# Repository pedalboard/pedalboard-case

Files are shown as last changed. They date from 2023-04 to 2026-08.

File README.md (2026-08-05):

# pedalboard-case

Mechanical 3D models enclosing the hardware.

The parts are created with openscad 2021.01

## Parts

<table>
<tr>
    <th>Part</th>
    <th>Description</th>
    <th>Image</th>
</tr>
<tr>
    <td><a href="./generated/side-panel-template.pdf">Side Panel Drill Template</a></td>
    <td>
       1:1 printable PDF for marking all side panel and back panel holes:
       6 jack holes (10mm), 2 MIDI/3.5mm holes (6mm), USB-A slot (8mm drill),
       and barrel jack (8mm). Align to top edge of case.
       Regenerate with <code>python3 parts/side-panel-template.py</code>.
    </td>
    <td></td>
</tr>
<tr>
    <td><a href="./generated/display-cutout-template.pdf">Front Panel Cutting Template</a></td>
    <td>
       1:1 printable PDF for marking all front panel holes: 6 button holes (ø22.3mm),
       2 encoder holes (ø22.3mm), 2 display cutouts (34.5×36.7mm), 2 light pipe holes (ø6mm),
       and 8 bezel mount holes (ø4mm). Print at 100% scale on A4.
    </td>
    <td></td>
</tr>
<tr>
    <td><a href="./parts/top-panel-gcode.py">CNC G-code</a></td>
    <td>
       G-code for CNC milling the top panel. Default: 4mm single flute downcut,
       300mm/min feed, 0.3mm depth/pass. Origin: case center (probe both sides).
       Regenerate with <code>python3 parts/top-panel-gcode.py</code>.
    </td>
    <td></td>
</tr>
<tr>
<tr>
    <td><a href="./parts/top-panel-engraving.yaml">Engraving Design</a></td>
    <td>
       Panel label engraving for the powder-coated top surface.
       Button labels A–F, encoder labels Vol/Gain, LED labels Mode/Mon,
       and I/O labels on all four edges. V-bit engraving with surface
       height map compensation via <a href="https://github.com/laenzlinger/plates">plates</a>.
       Run <code>python3 cnc/engrave-setup.py</code> to probe the surface
       and generate <code>engraving.nc</code>.
    </td>
    <td></td>
</tr>
<tr>
    <td><a href="./generated/actuator-assembly.stl">Switch Actuator</a></td>
    <td>
       <a href="https://www.cliffuk.co.uk/products/switches/FC7125.pdf">Manufactured by Cliff</a>.
    </td>
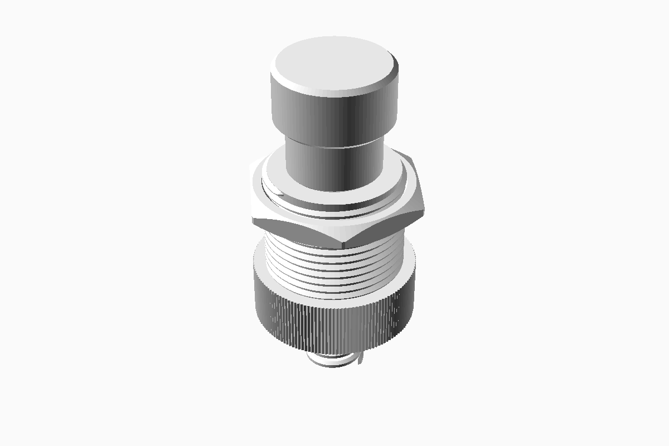
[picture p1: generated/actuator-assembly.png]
    <td></td>
</tr>
<tr>
    <td><a href="./generated/led-ring-washer.stl">Button Washer</a></td>
    <td>
       LED ring washer for Switch Actuator. Print with transparent PETG.
    </td>
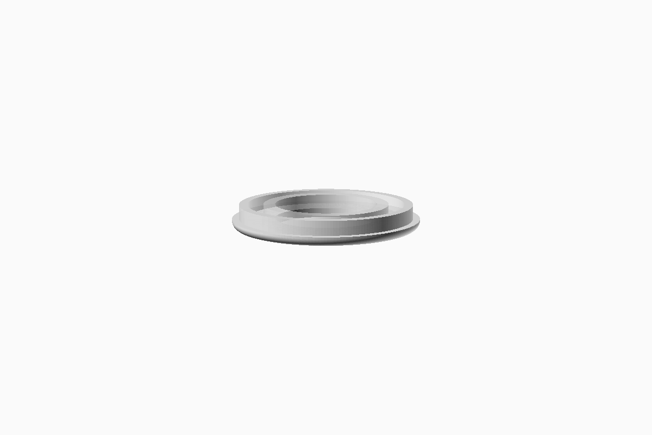
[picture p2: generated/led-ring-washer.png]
    <td></td>
</tr>
<tr>
    <td><a href="./generated/led-ring-rotary-washer.stl">Rotary Encoder Washer</a></td>
    <td>
       LED ring washer for Rotary Encoder. Print with transparent PETG.
    </td>
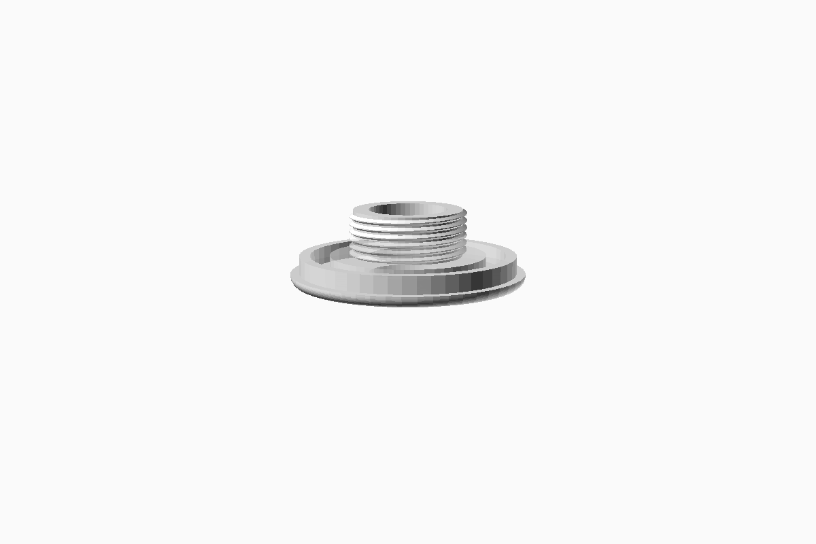
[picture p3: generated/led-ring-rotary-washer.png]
    <td></td>
</tr>
<tr>
    <td><a href="./generated/light-pipe.stl">Light Pipe</a></td>
    <td>
       Print with transparent PETG.
    </td>
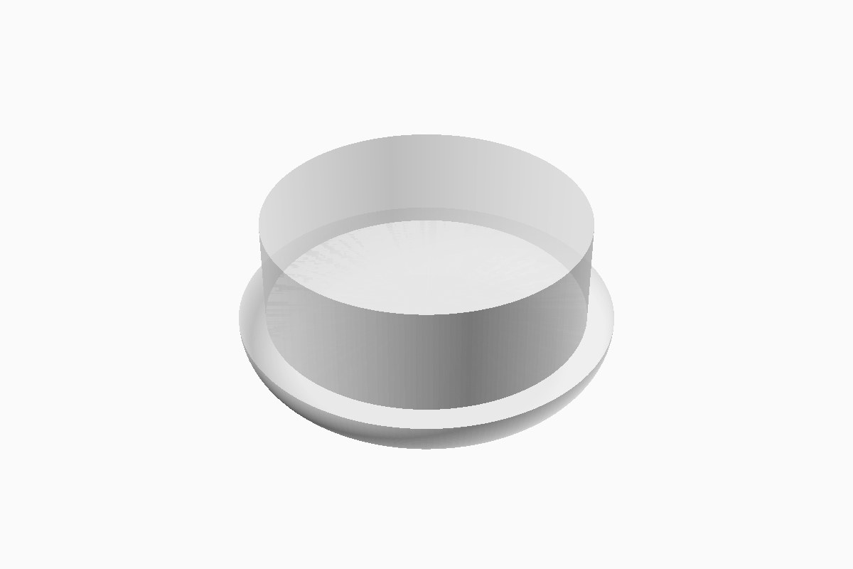
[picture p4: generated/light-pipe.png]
    <td></td>
</tr>

<tr>
    <td><a href="./generated/display-bezel.stl">Display Bezel</a></td>
    <td>
       Display bezel for 128x128 pixel OLED Display (1.5")
    </td>
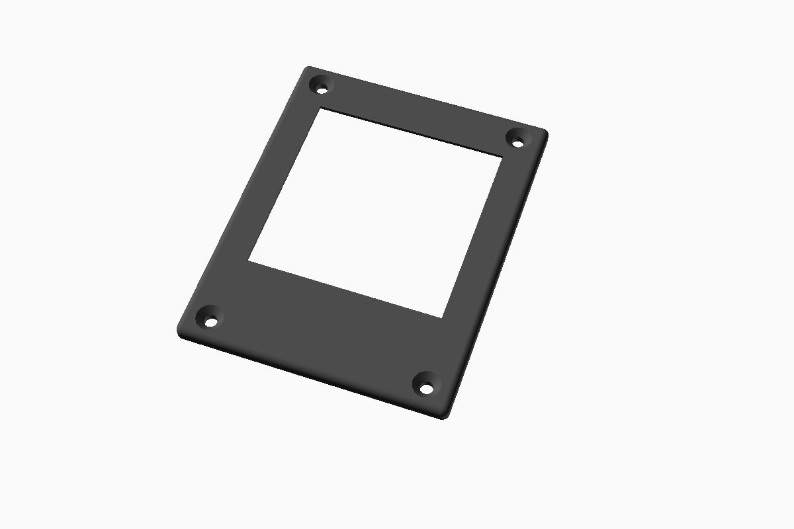
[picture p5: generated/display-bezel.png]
    <td></td>
</tr>
 <tr>
    <td><a href="./generated/display-mounting-rack.stl">Display Mounting Rack</a></td>
    <td>
       Display mounting rack for 128x128 pixel OLED Display (1.5")
    </td>
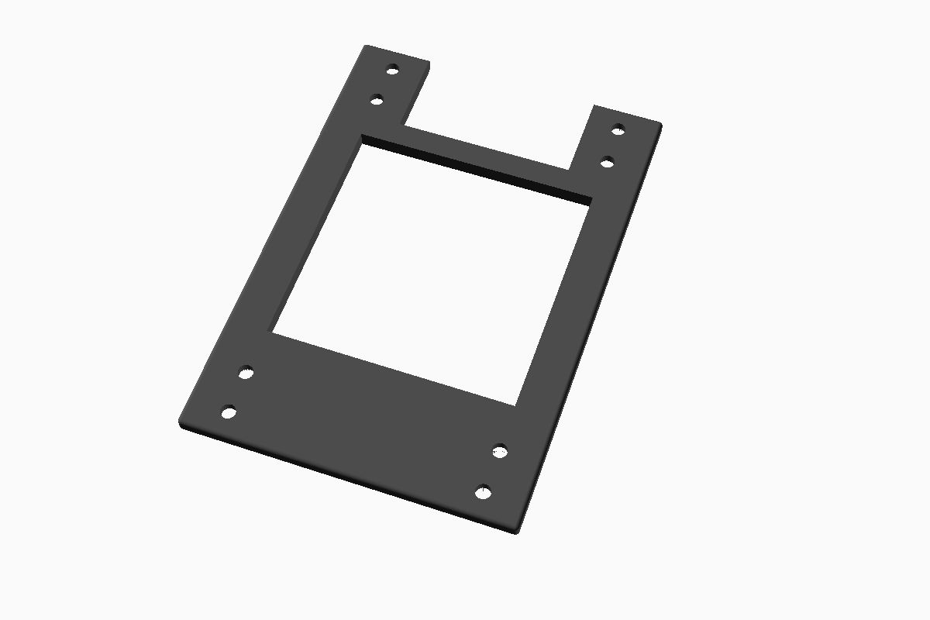
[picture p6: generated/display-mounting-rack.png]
    <td></td>
</tr>
<tr>
    <td><a href="./generated/oled-display.stl">OLED Display</a></td>
    <td>
      Model of the 128x128 pixel OLED display (1.5")
    </td>
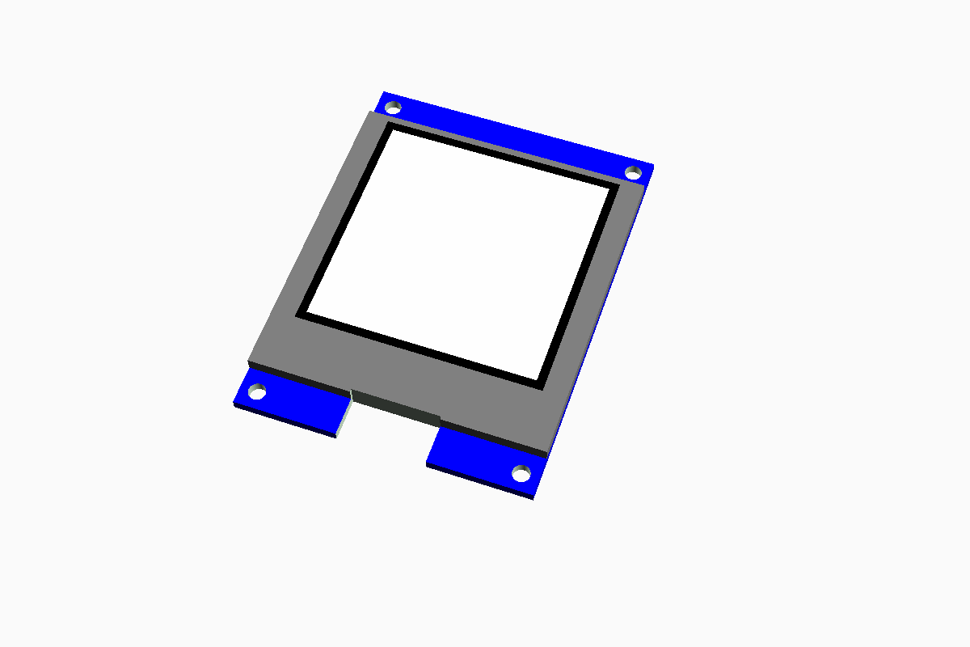
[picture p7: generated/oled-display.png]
    <td></td>
</tr>
 <tr>
    <td><a href="https://github.com/laenzlinger/cnc/tree/main/parts/fixture-plate">CNC Fixture Plate</a></td>
    <td>
       15mm MDF fixture plate for milling the top panel on the SRcnc.
       Maintained in the <a href="https://github.com/laenzlinger/cnc">cnc repo</a>.
    </td>
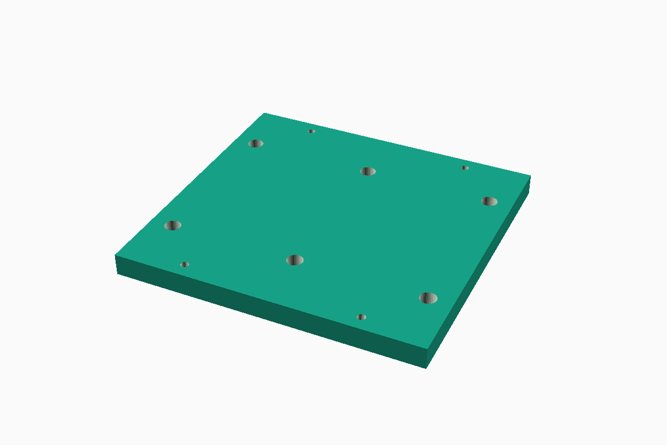
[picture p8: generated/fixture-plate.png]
    <td></td>
</tr>
<tr>
    <td><a href="./parts/led-ring-flush.scad">LED Ring (flush mount)</a></td>
    <td>
       2mm plexiglass stepped ring for flush-mounted LED illumination.
       ø24mm top lip (1mm) sits in case recess, ø22mm bottom (1mm) drops into button hole,
       ø14mm center hole for actuator. Acts as light diffuser for SK6805-EC15 LEDs.
       CNC cut from plexiglass sheet with 4mm downcut endmill.
    </td>
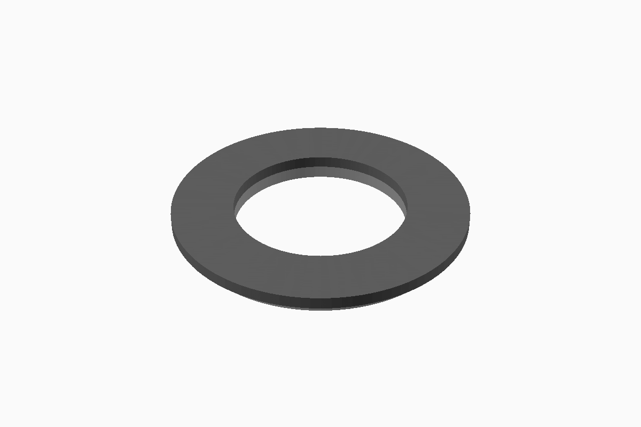
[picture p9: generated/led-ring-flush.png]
    <td></td>
</tr>
<tr>
    <td><a href="./parts/display-window-flush.scad">Display Window (flush mount)</a></td>
    <td>
       2mm plexiglass stepped rectangle for flush-mounted OLED display.
       36.5×38.7mm top lip (1mm) sits in case recess, 34.1×36.3mm bottom (1mm) drops into
       display cutout. Solid window — display visible through plexiglass.
       2mm corner radius (4mm endmill). CNC cut from plexiglass sheet.
    </td>
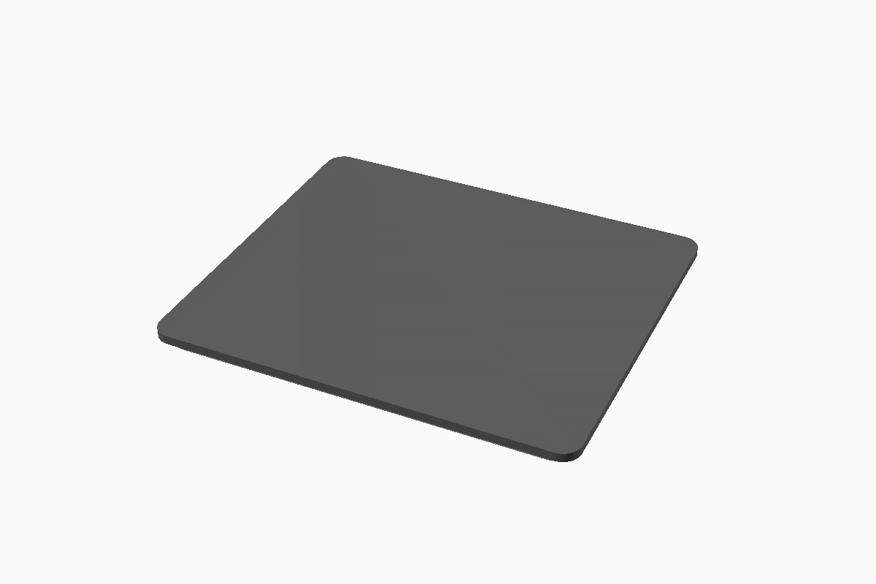
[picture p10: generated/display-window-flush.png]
    <td></td>
</tr>
<tr>
    <td><a href="./parts/lightpipe-disc.scad">Light Pipe Disc (flush mount)</a></td>
    <td>
       2mm plexiglass disc for flush-mounted light pipe.
       6mm diameter, press-fits into light pipe hole.
       CNC cut from plexiglass sheet with 4mm downcut endmill.
    </td>
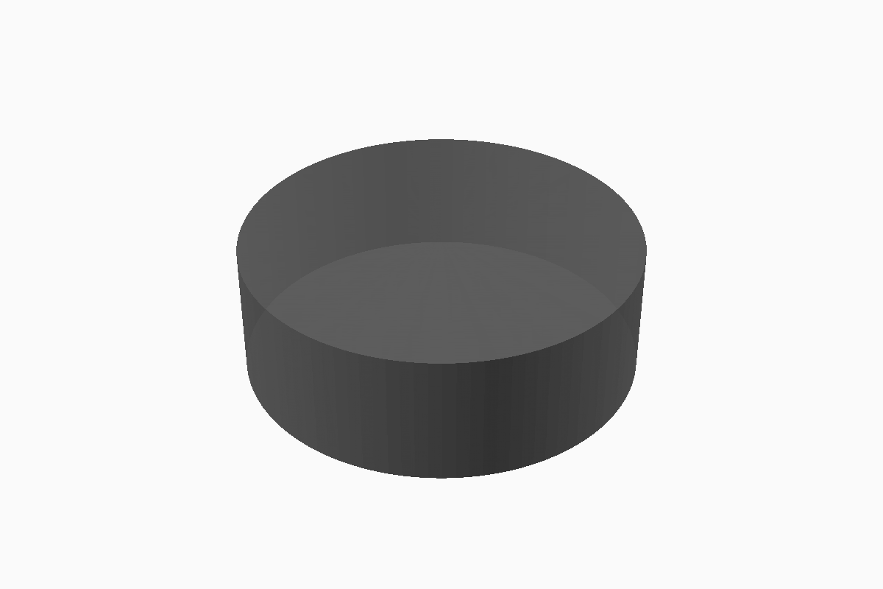
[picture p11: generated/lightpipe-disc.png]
    <td></td>
</tr>
</table>

## 3D printable files

See [STL files](./generated)

Some parts are available in two variants:

| Function | 3D printed (PETG) | CNC plexiglass |
|---|---|---|
| Button LED ring | `led-ring-washer.stl` | `led-ring-flush.scad` |
| Encoder LED ring | `led-ring-rotary-washer.stl` | `led-ring-flush.scad` |
| Display window | `display-bezel.stl` + mounting rack | `display-window-flush.scad` |
| Light pipe | `light-pipe.stl` | `lightpipe-disc.scad` |

**3D printed** — uses transparent PETG, easier to make, rougher finish.
Good for prototyping.

**CNC plexiglass** — cut from 2mm translucent acrylic sheet, flush-mount
with stepped profile, cleaner look. Requires CNC and `plexi-cut.py`.

## Top panel generation

All top panel machining outputs are derived from the [pedalboard-display](https://github.com/pedalboard/pedalboard-display) KiCad PCB:

```
pedalboard-display.kicad_pcb
  → extract-coords.py → top-panel-coords.json
  → top-panel-gcode.py → top-panel.nc
  → top-panel-template.py → display-cutout-template.svg/.pdf
```

Regenerate after PCB changes:

```bash
cd parts && make panel
```

## CNC milling workflow

The top panel is milled on the SRcnc machine (Hammond 1590DD die cast aluminium,
open-side-down fixture). Two separate operations: hole cutting, then engraving.

See [cnc/README.md](./cnc/README.md) for full setup instructions, probing geometry,
and testing.

### 1. Cut holes

```bash
cd cnc
python3 probe-setup.py    # close gSender first — script owns the serial port
# → generates top-panel.nc
# Open gSender, load top-panel.nc, dial 1, WD-40, run at 150% feed
```

Tool: 4mm single flute downcut, 300mm/min, 0.3mm depth/pass.

### 2. Engrave labels

```bash
python3 engrave-setup.py  # close gSender first
# → probes 6×10 surface height map, generates engraving.nc
# Open gSender, load engraving.nc, run
```

Tool: 60° V-bit, 150mm/min. The height map compensates for powder coat
variation and panel crown so the V-bit follows the actual surface.
`engrave-setup.py` runs independently — no need to run `probe-setup.py` first.

**Manual G-code generation (without height map):**

```bash
python3 parts/top-panel-gcode.py --angle -0.23 --z-offsets z-offsets.json > top-panel.nc
```

**Origin modes:**
- `center` (default) — G54 X0 Y0 at case center, requires probing edges
- `corner` — G54 X0 Y0 at front-left corner of case top surface

## Plexiglass parts

All flush-mount plexiglass parts (LED rings, display windows, light pipe discs)
are cut from 2mm acrylic sheet (translucent black tea / smoke).

**Generate G-code:**

```bash
# Test cut (1 of each part)
python3 parts/plexi-cut.py > generated/plexi-cut.nc

# Production (8 rings, 2 windows, 2 discs)
python3 parts/plexi-cut.py --production > generated/plexi-production.nc
```

**Cutting parameters:**
- Tool: 4mm single flute downcut
- Spindle: Makita dial 3 (~17,000 RPM)
- Feed: 500 mm/min
- Depth/pass: 0.25mm
- Fixture: double-sided tape, leave protective film on

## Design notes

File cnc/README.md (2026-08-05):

# cnc/

Automated CNC setup scripts for the Hammond 1590DD top panel —
hole cutting and engraving on powder-coated aluminium.

## Files

| File | Purpose |
|---|---|
| `grbl.py` | Shared GRBL/grblHAL serial protocol and probe helpers |
| `probe-setup.py` | Full setup for hole cutting: edges, angle, per-feature Z, G-code |
| `engrave-setup.py` | Setup for engraving: edges, angle, surface height map, engraving G-code |
| `mock-machine.py` | Machine simulator for testing without real hardware |
| `run_test.py` | Test runner (runs setup scripts against simulator) |

## Setup

```bash
pip install pyserial==3.5
```

## Workflow Overview

```
1. Mount case on fixture plate (open-side-down, centered at ~X=110 Y=190)
2. Close gSender

── HOLE CUTTING ──────────────────────────────────────────────────────────────
3. python3 cnc/probe-setup.py
   → installs 3D probe, finds centre+angle, per-feature Z offsets, touch plate Z
   → generates top-panel.nc
4. Open gSender, connect, load top-panel.nc, run

── ENGRAVING ─────────────────────────────────────────────────────────────────
5. python3 cnc/engrave-setup.py
   → installs 3D probe, finds centre+angle, probes 6×10 height map (38 points),
     skips holes, saves heightmap.json, generates engraving.nc via plates.py
   → installs V-bit, touch plate Z
6. Open gSender, connect, load engraving.nc, run
```

---

## probe-setup.py

Full automated setup for hole cutting.

**Usage:**
```bash
python3 probe-setup.py                     # full run
python3 probe-setup.py --dry-run           # print commands without connecting
python3 probe-setup.py --port /tmp/cnc-sim # test with simulator

# Rework (holes already cut — skip feature probing):
python3 probe-setup.py --skip-feature-probing --z-probe-offset 10 0
```

**Steps:**
1. Home machine (Z → X → Y)
2. Pause: install 3D probe
3. Probe spoilboard Z reference
4. Probe 5 case edges → centre + rotation angle, set G54 X0 Y0
5. Probe case surface Z at centre
6. Probe Z at 12 feature centres (buttons, encoders, displays, LEDs)
7. Pause: swap to cutting tool
8. Probe Z with touch plate → set G54 Z0
9. Generate `top-panel.nc` with angle + Z offsets

**Outputs:** `top-panel.nc`, `z-offsets.json`

---

## engrave-setup.py

Setup for engraving on the powder-coated panel surface.

The powder coat is non-conductive and ~0.1mm thick — the 3D mechanical
probe measures the actual coated surface. A 6×10 height map grid is probed
across the panel (~20mm spacing), skipping all hole positions. The height map
is applied to the engraving G-code via `plates.py --heightmap` so the V-bit
follows the actual surface rather than a flat plane.

**Usage:**
```bash
python3 engrave-setup.py                     # full run
python3 engrave-setup.py --dry-run           # print commands without connecting
python3 engrave-setup.py --port /tmp/cnc-sim # test with simulator

# If case centre has a hole (use an offset reference point):
python3 engrave-setup.py --z-probe-offset 10 0
```

**Steps:**
1. Home machine (Z → X → Y)
2. Pause: install 3D probe
3. Probe spoilboard Z reference
4. Probe 5 case edges → centre + rotation angle, set G54 X0 Y0
5. Probe reference surface Z at centre
6. Probe 6×10 grid (38 points after skipping holes) → `heightmap.json`
7. Generate `engraving.nc` via `plates.py --heightmap`
8. Pause: swap to V-bit
9. Probe Z with touch plate → set G54 Z0

**Outputs:** `engraving.nc`, `heightmap.json`

### Height Map Grid

```
Grid: 6 cols × 10 rows  (~20mm spacing)
Bounds: ±53.9mm X, ±87.9mm Y (3mm margin from each edge)
Hole avoidance: buttons/encoders r=14.2mm, LEDs r=6mm,
                bezel holes r=5mm, displays 25×21mm rect
Skipped points filled by nearest-neighbour for complete JSON grid.
```

---

## mock-machine.py

GRBL/grblHAL machine simulator for testing without real hardware.

```bash
python3 mock-machine.py                       # nominal case
python3 mock-machine.py --angle 0.5           # 0.5° rotation
python3 mock-machine.py --offset-x 2.0        # case shifted 2mm in X
python3 mock-machine.py --crown 0.3           # 0.3mm sinusoidal surface crown
python3 mock-machine.py --angle 0.3 --crown 0.4  # combined
```

The `--crown` option simulates a typical die-cast aluminium panel: the surface
is highest at the centre and tapers to zero at the edges following a
cosine profile. Typical powder-coated cases: 0.3–0.5mm.

---

## Testing

```bash
make test           # run probe-setup.py against simulator
make test-engrave   # run engrave-setup.py against simulator (with 0.3mm crown)

# Manual testing with custom parameters:
python3 run_test.py --angle 0.5
python3 run_test.py --engrave --crown 0.5
```

### Testing with two terminals

```bash
# Terminal 1 — start simulator
python3 mock-machine.py --angle 0.3 --crown 0.3

# Terminal 2 — run setup
python3 probe-setup.py --port /tmp/cnc-sim
# or
python3 engrave-setup.py --port /tmp/cnc-sim
```

---

## XY Probing Geometry

Same for both scripts — 5 edge probes, no case dimension assumptions:

```
              You stand here (Y=0)

    Y
    ↑
    │
    ┊                  ┌───────────────────────┐
250 ┊ ─ ─ ─ ②·→→→→→→→→→█           ·⑤          │
    │                  │       X=110,Y=291     │
190 ┊                  │       CENTER          █←·③
    │                  │     (110, 190)        │ X=177
130 ┊ ─ ─ ─ ①·→→→→→→→→→█                       │
    ┊                  └───────────────────────┘
 89 ┊                          ·④
    └──────────────────────────── → X
   0      43  53              167 177  220

  ① X- front  Y=130  → +X   left edge + angle pt 1
  ② X- back   Y=250  → +X   left edge + angle pt 2
  ③ X+ edge   Y=190  ← -X   right edge
  ④ Y- edge   X=110  ↑ +Y   front edge
  ⑤ Y+ edge   X=110  ↓ -Y   back edge

  X centre = (avg(①,②) + ③) / 2
  Y centre = (④ + ⑤) / 2
  Angle    = atan2(②x − ①x, 120mm)
```

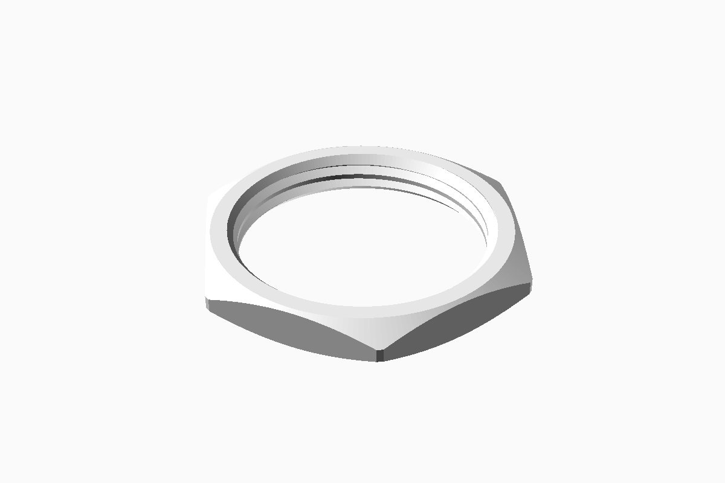
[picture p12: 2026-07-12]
generated/actuator-nut.png

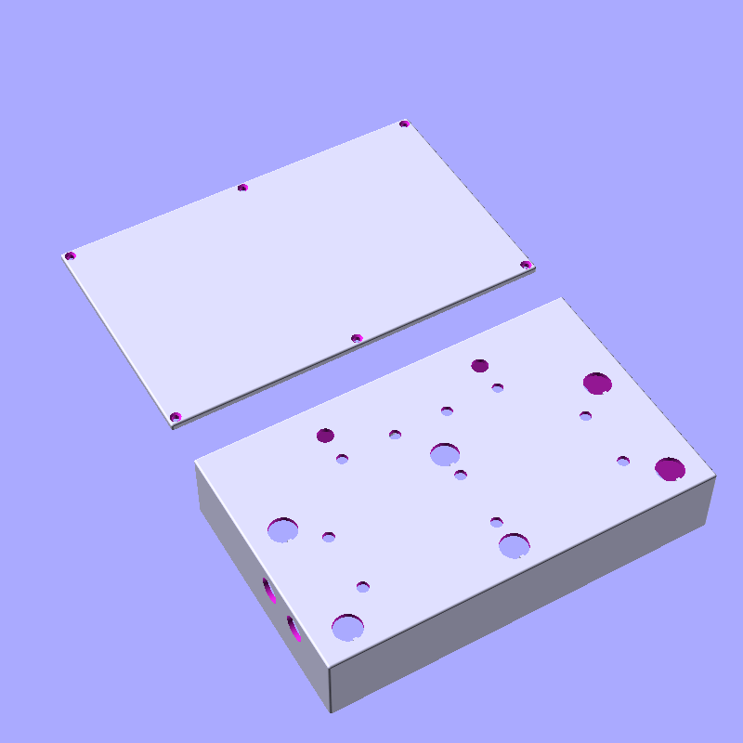
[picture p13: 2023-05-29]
generated/pedalboard-case.png

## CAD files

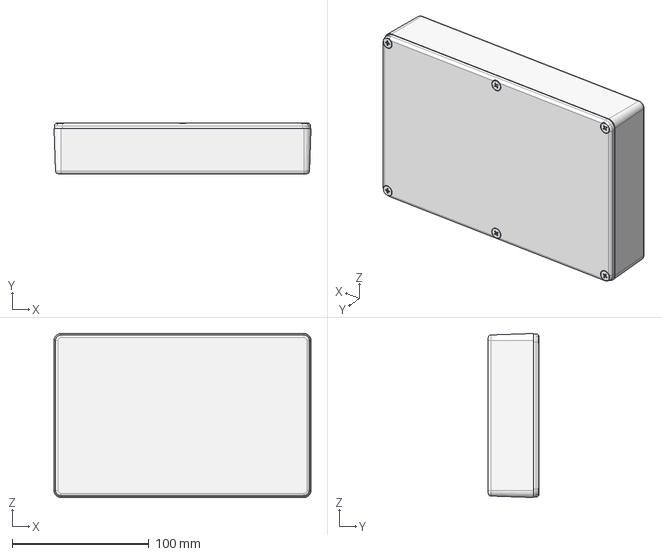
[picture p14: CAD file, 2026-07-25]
1590DD.stp
188.0 x 37.0 x 120.0 mm

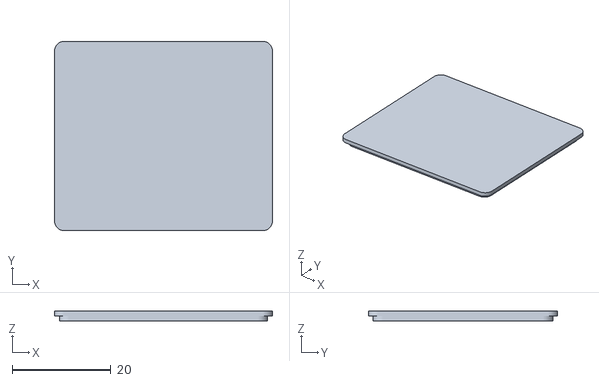
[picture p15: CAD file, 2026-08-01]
generated/display-window-flush.stl
44.2 x 38.4 x 2.00

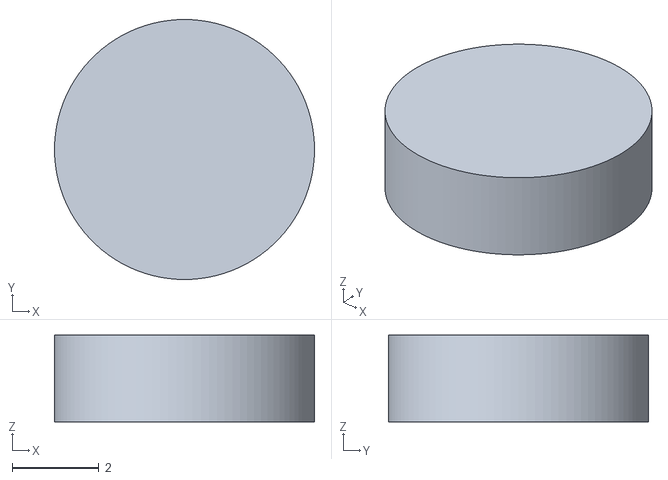
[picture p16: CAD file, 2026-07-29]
generated/lightpipe-disc.stl
6.00 x 6.00 x 2.00

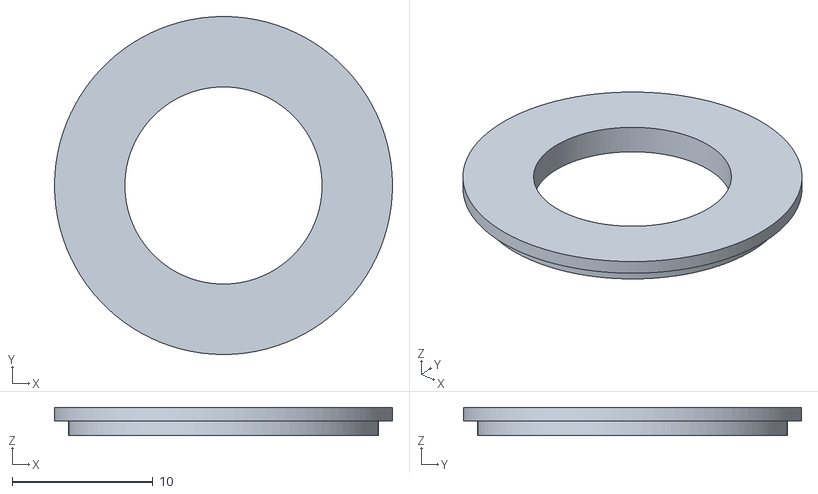
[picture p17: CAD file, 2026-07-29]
generated/led-ring-flush.stl
24.0 x 24.0 x 2.00

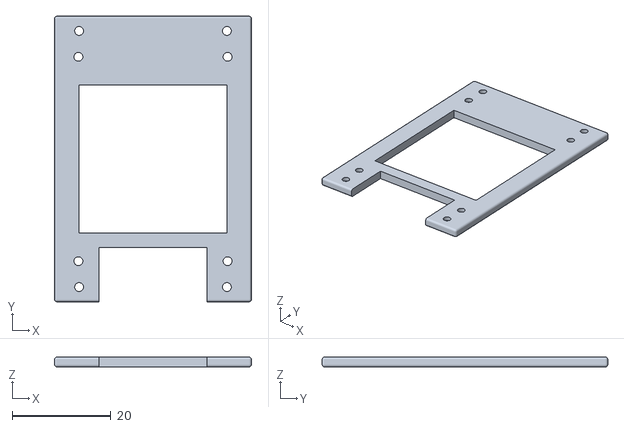
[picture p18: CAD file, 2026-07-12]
generated/display-mounting-rack.stl
40.0 x 58.0 x 2.00

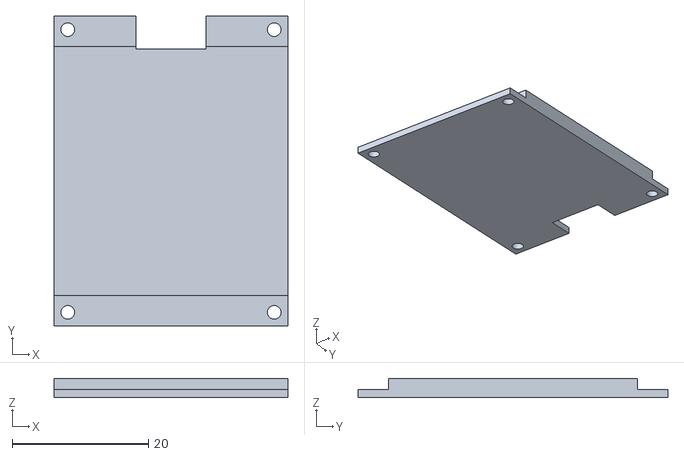
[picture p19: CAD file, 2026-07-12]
generated/oled-display.stl
34.3 x 45.5 x 2.83

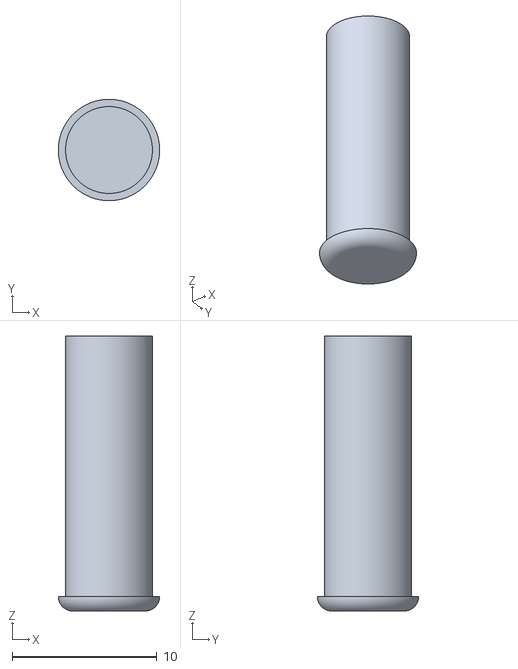
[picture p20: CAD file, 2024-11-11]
generated/light-pipe.stl
7.00 x 7.00 x 19.0

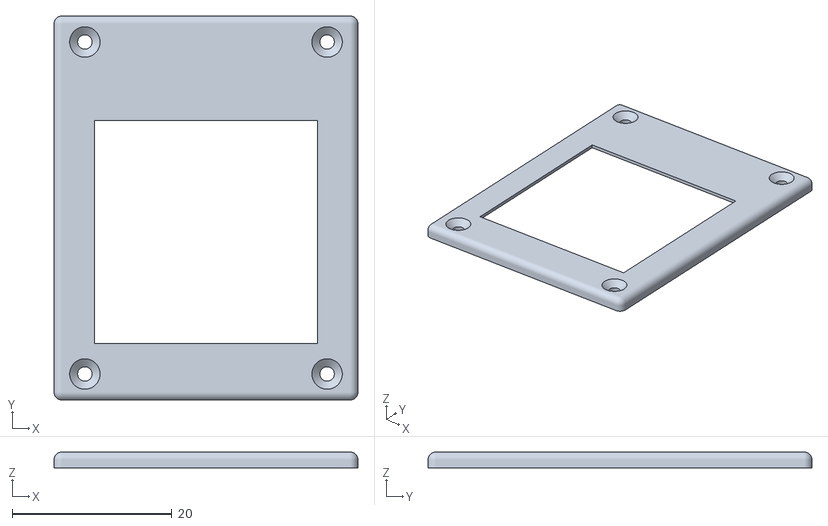
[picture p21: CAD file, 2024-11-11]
generated/display-bezel.stl
38.0 x 48.0 x 2.00

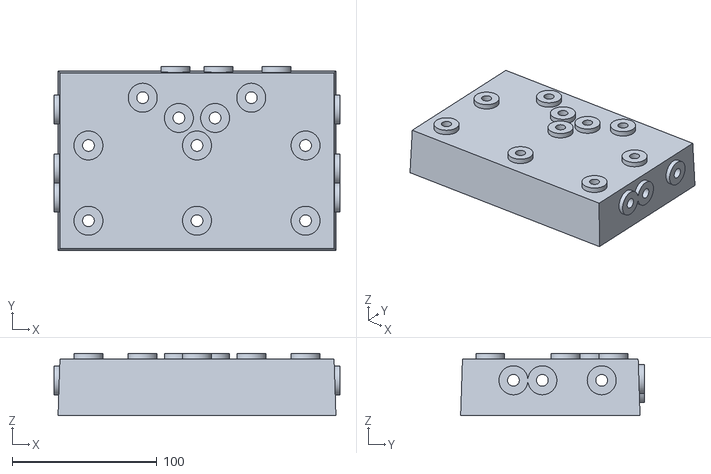
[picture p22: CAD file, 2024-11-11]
generated/drill-jig.stl
197.6 x 127.0 x 43.0

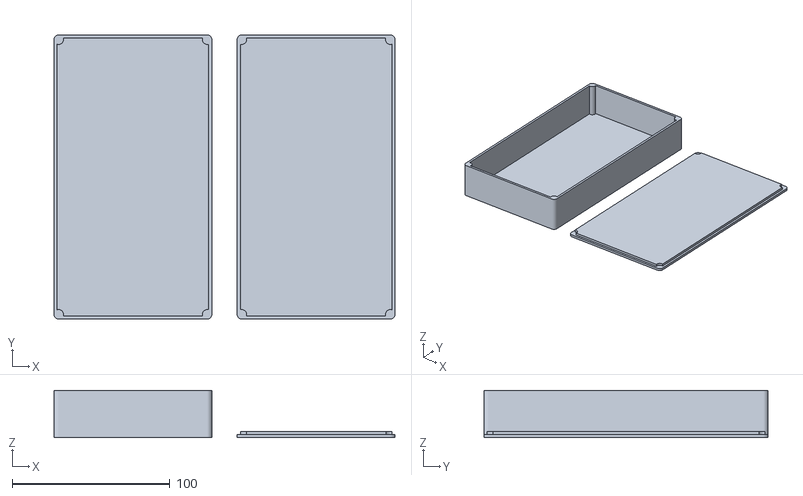
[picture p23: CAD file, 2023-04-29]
generated/pedalboard-case.stl
216.0 x 180.0 x 30.0

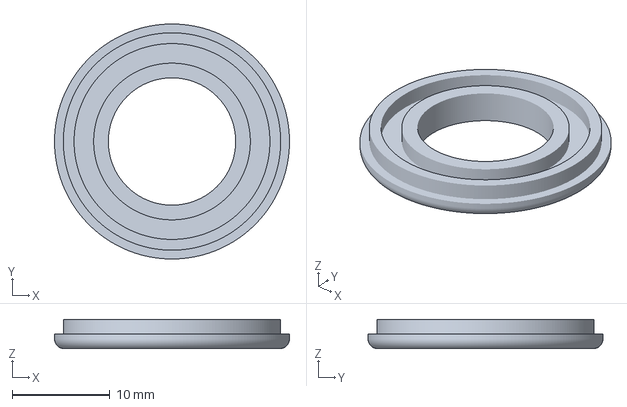
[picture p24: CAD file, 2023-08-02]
slicer/led-ring-washer.3mf
24.0 x 24.0 x 3.00 mm

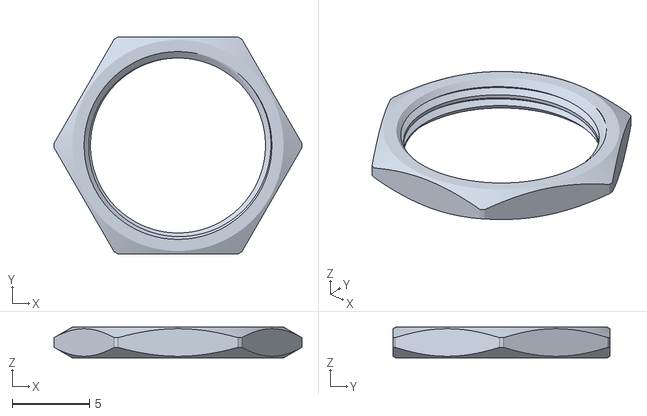
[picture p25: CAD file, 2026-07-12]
generated/actuator-nut.stl
16.0 x 14.0 x 2.00

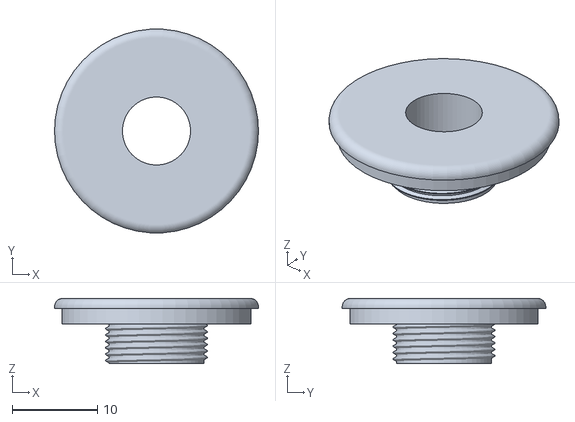
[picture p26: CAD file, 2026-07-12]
generated/led-ring-rotary-washer.stl
24.0 x 24.0 x 7.70

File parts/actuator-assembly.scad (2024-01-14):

include <lib/actuator.scad>

$fn=100;

pcb_thickness = 1.6;

actuator();
up(5+4.5+pcb_thickness) actuator_nut();
// up(5+2.5+pcb_thickness) led_ring_washer();

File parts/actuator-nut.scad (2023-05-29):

include <lib/actuator.scad>

$fn=200;

actuator_nut();

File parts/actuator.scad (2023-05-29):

include <BOSL2/std.scad>
include <BOSL2/threading.scad>

// based on https://www.cliffuk.co.uk/products/switches/FC7125.pdf

$fn=200;

module actuator() {
    screwlen = 14.3;
    up(screwlen/2) threaded_rod(d=12,l=screwlen,pitch=0.75);
    up(screwlen+2.05+5) cyl(l=5.1, d=10, chamfer=0.4);
    up(screwlen+2.6) cyl(l=5.2, d=8, chamfer=0.2);
    up(2.5) cyl(l=5, d=14, texture="ribs", tex_scale=0.1, tex_size=[0.3,0.3]);
    down(3) thread_helix(d2=3, d1=4.8, pitch=1, thread_depth=0.3, flank_angle=35, turns=6.5);
}

actuator();

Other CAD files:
parts/display-bezel.scad
parts/display-mounting-rack.scad
parts/display-window-flush.scad
parts/led-ring-flush.scad
parts/led-ring-rotary-washer.scad
parts/led-ring-washer.scad
parts/light-pipe.scad
parts/lightpipe-disc.scad
parts/oled-display.scad

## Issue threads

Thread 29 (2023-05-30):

Refactoring: Use BOSL2

laenzlinger, 2023-05-30:
BOSL2 supports threads and allows so much nicer code

laenzlinger, 2024-01-09:
no need for refactoring, the case stragety has changed

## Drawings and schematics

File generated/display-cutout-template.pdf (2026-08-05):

# Pedalboard Case Cutting Template (1:1)

Display cutout: 42.5×36.7mm. Print at 100% on A4.

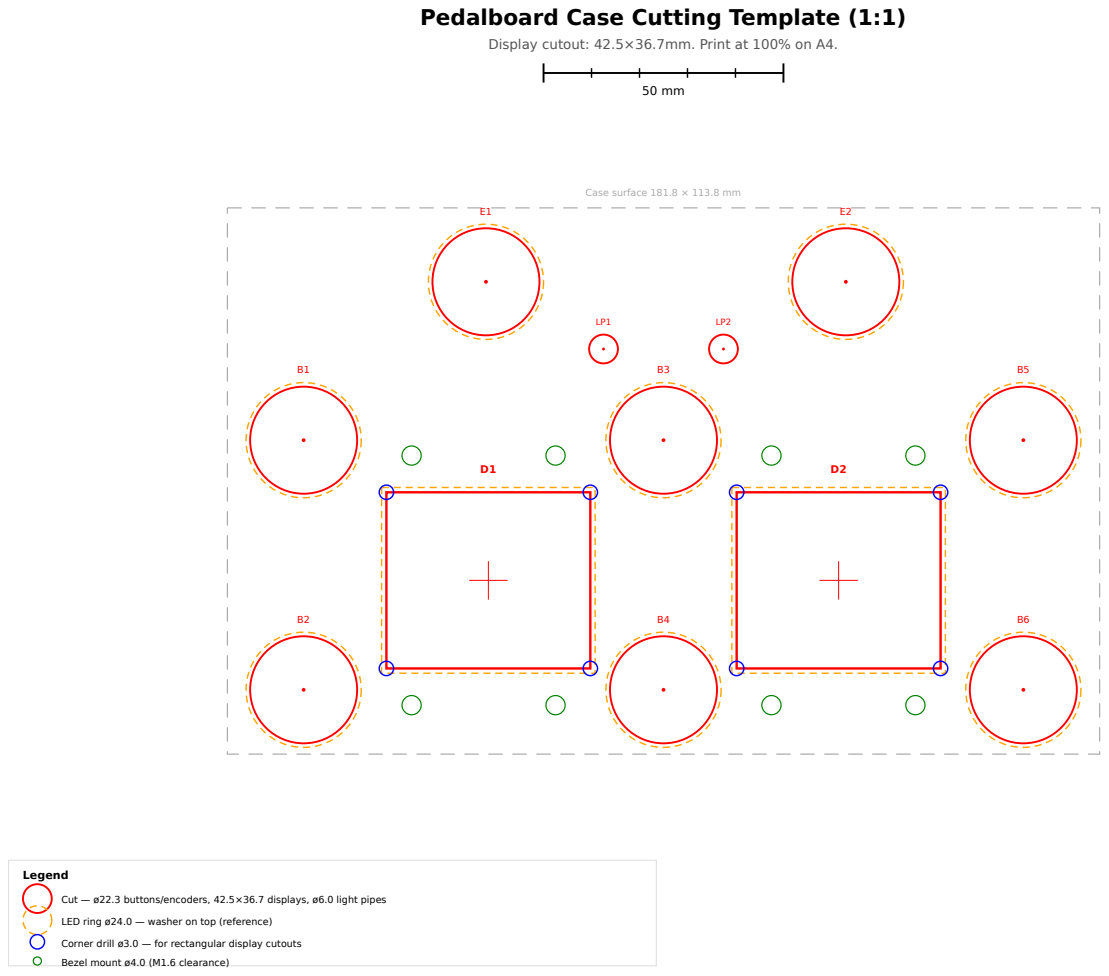
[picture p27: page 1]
Legend

Case surface 181.8 × 113.8 mm

Cut — ø22.3 buttons/encoders, 42.5×36.7 displays, ø6.0 light pipes

LED ring ø24.0 — washer on top (reference)

Corner drill ø3.0 — for rectangular display cutouts
Bezel mount ø4.0 (M1.6 clearance)

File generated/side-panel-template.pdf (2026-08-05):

## Left side (looking from outside) (120mm x 37mm)

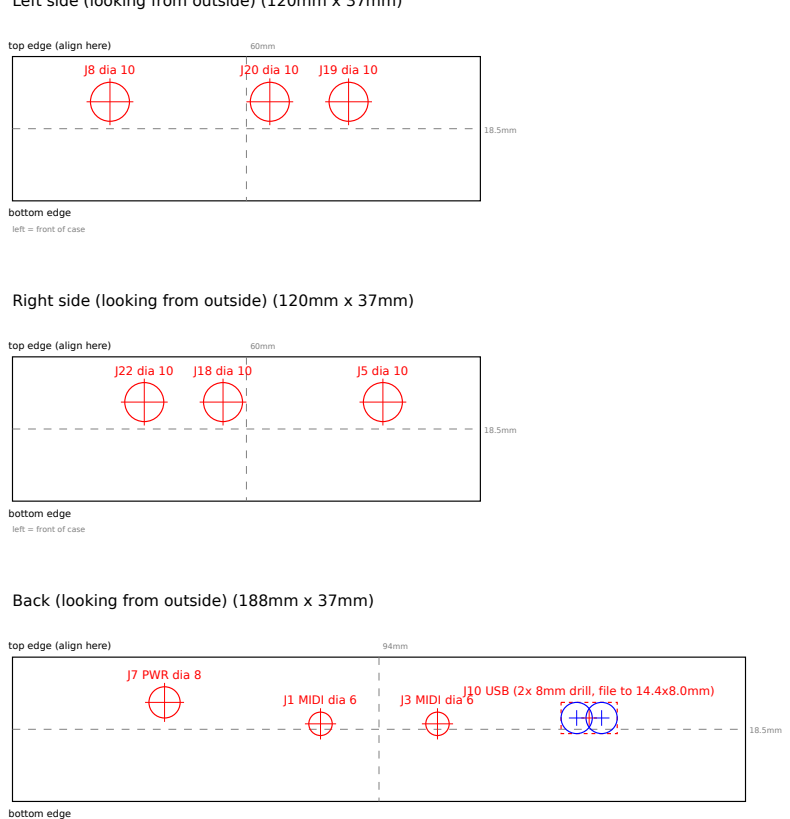
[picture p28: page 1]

top edge (align here)

left = front of case

Right side (looking from outside) (120mm x 37mm)

Back (looking from outside) (188mm x 37mm)

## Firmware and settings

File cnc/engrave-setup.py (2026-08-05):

#!/usr/bin/env python3
"""
engrave-setup.py — Surface height map probing for powder-coated panel engraving.

Probes a grid of Z heights across the Hammond 1590DD top panel surface,
skipping all hole positions. Saves a heightmap.json for use with plates.py
--heightmap to compensate for surface variation when engraving.

Workflow:
  1. Home machine
  2. Pause: install 3D probe
  3. Probe spoilboard Z reference
  4. Probe X-, X+, Y-, Y+ edges → case center + rotation angle, set G54 X0 Y0
  5. Probe surface Z at grid points (skipping holes)
  6. Save heightmap.json
  7. Generate engraving.nc via plates.py --heightmap
  8. Pause: remove 3D probe, install V-bit
  9. Probe Z with touch plate, set G54 Z0
  10. Ready to engrave

Usage:
    python3 engrave-setup.py
    python3 engrave-setup.py --dry-run
    python3 engrave-setup.py --port /tmp/cnc-sim   # test with simulator

Preconditions:
    - gSender disconnected (script owns /dev/cnc)
    - Case mounted open-side-down on fixture plate
    - Holes already cut (from probe-setup.py + top-panel.nc run)
    - Machine in idle state
"""

import argparse
import json
import math
import sys
from pathlib import Path

from grbl import (
    HOMING_TIMEOUT,
    GrblConnection,
    check_plausibility,
    pause,
    probe_edge_double,
    probe_spoilboard,
    probe_z_double,
    probe_z_surface,
)

# Add plates project to path (editable install doesn't expose top-level modules)
_PLATES_DIR = Path(__file__).parent / "../../../laenzlinger/plates"
_PLATES_DIR = _PLATES_DIR.resolve()
if _PLATES_DIR.exists() and str(_PLATES_DIR) not in sys.path:
    sys.path.insert(0, str(_PLATES_DIR))

# === MACHINE CONFIGURATION ===

PORT = "/dev/cnc"
BAUD = 115200

SAFE_Z             = 10.0   # mm — safe Z for rapids
GRID_TRAVERSE_Z    =  3.0   # mm — Z above surface for moves between probe points
FEED_FAST          = 100.0  # mm/min
FEED_SLOW          =  20.0  # mm/min
PROBE_TIP_RADIUS   =  2.0   # mm — HLTNC 3D probe tip radius
TOUCH_PLATE_THICKNESS = 19.25  # mm

# Case geometry (machine coords)
CASE_CENTER_X       = 110.0
CASE_CENTER_Y       = 190.0
CASE_HALF_WIDTH     = 113.8 / 2.0   # X half-extent (short axis)
CASE_HALF_HEIGHT    = 181.8 / 2.0   # Y half-extent (long axis)
CASE_HEIGHT_NOMINAL = 33.0           # mm — case wall height open-side-down
XY_PROBE_BELOW_SURFACE = 5.0

APPROACH_CLEARANCE  = 20.0
PROBE_TRAVEL_Z      = 80.0

ANGLE_PROBE_Y_FRONT = CASE_CENTER_Y - 60.0
ANGLE_PROBE_Y_BACK  = CASE_CENTER_Y + 60.0

TOOL_CHANGE_X = 110.0
TOOL_CHANGE_Y = 5.0

SPOILBOARD_PROBE_X = 10.0
SPOILBOARD_PROBE_Y = 190.0

# Plausibility tolerances
EXPECTED_CASE_WIDTH  = 113.8
EXPECTED_CASE_HEIGHT = 181.8
MAX_WIDTH_ERROR  = 10.0
MAX_ANGLE_DEG    =  5.0
MAX_CENTER_ERROR = 30.0

# === GRID CONFIGURATION ===

# 3mm margin from each edge (inside the 1mm fillet radius + clearance)
GRID_MARGIN = 3.0

# Grid in G54 work coordinates (origin = case centre)
# Panel: 181.8 (Y long) x 113.8 (X short) → half-extents minus margin
GRID_X_HALF = CASE_HALF_WIDTH  - GRID_MARGIN   # 53.9mm
GRID_Y_HALF = CASE_HALF_HEIGHT - GRID_MARGIN   # 87.9mm

# ~20mm spacing → 6 cols x 10 rows = 60 points (38 probed after hole avoidance)
GRID_COLS = 7
GRID_ROWS = 8

# Hole avoidance: probe tip radius + 1mm safety margin
_HOLE_MARGIN = PROBE_TIP_RADIUS + 1.0   # 3.0mm extra

# Paths
SCRIPT_DIR     = Path(__file__).parent
REPO_ROOT      = SCRIPT_DIR.parent
ENGRAVING_YAML = REPO_ROOT / "parts" / "top-panel-engraving.yaml"
HEIGHTMAP_FILE = REPO_ROOT / "heightmap.json"
ENGRAVING_NC   = REPO_ROOT / "engraving.nc"
COORDS_JSON    = REPO_ROOT / "parts" / "top-panel-coords.json"


# === HOLE AVOIDANCE ===

def _build_hole_list(angle_deg: float) -> list:
    """Return list of (type, cx, cy, radius_or_None, half_w_or_None, half_h_or_None).

    All coordinates in G54 work coords (origin at case centre, Y+ = toward back).
    Applies angle correction to match the probed case orientation.

    Coordinate conversion from panel_coords (origin=corner, landscape):
      work_x = panel_x - PANEL_W/2
      work_y = panel_y - PANEL_H/2   (panel Y=0=front, work Y- = front)
    """
    sys.path.insert(0, str(REPO_ROOT / "parts"))
    from panel_coords import load_coords, cnc_coords

    data   = load_coords(str(COORDS_JSON))
    # Use origin=corner to get landscape panel coords, then convert to work coords
    coords = cnc_coords(data, origin="corner", angle_deg=angle_deg)
    feats  = data["features"]

    PANEL_W = data["case"]["top_surface_width"]   # 181.8
    PANEL_H = data["case"]["top_surface_height"]  # 113.8

    def to_work(px, py):
        """Panel coords (origin=front-left, landscape) -> work coords (G54, origin=centre).

        Empirically verified (from panel_coords origin=center cross-check):
          work_x = -(panel_y - PANEL_H/2)   (machine X = short axis = panel Y direction)
          work_y =   panel_x - PANEL_W/2    (machine Y = long axis  = panel X direction)
        """
        return -(py - PANEL_H / 2), px - PANEL_W / 2

    holes = []

    # Circular holes — convert landscape panel coords to work coords
    for ox, oy in coords["buttons"]:
        # coords["buttons"] gives (portrait_cnc_x, portrait_cnc_y)
        # landscape: panel_x = portrait_cnc_y, panel_y = PANEL_H - portrait_cnc_x
        panel_x, panel_y = oy, PANEL_H - ox
        wx, wy = to_work(panel_x, panel_y)
        holes.append(("button", wx, wy,
                      feats["button_hole_diameter"] / 2 + _HOLE_MARGIN, None, None))
    for ox, oy in coords["encoders"]:
        panel_x, panel_y = oy, PANEL_H - ox
        wx, wy = to_work(panel_x, panel_y)
        holes.append(("encoder", wx, wy,
                      feats["encoder_hole_diameter"] / 2 + _HOLE_MARGIN, None, None))
    for ox, oy in coords["single_leds"]:
        panel_x, panel_y = oy, PANEL_H - ox
        wx, wy = to_work(panel_x, panel_y)
        holes.append(("led", wx, wy,
                      feats["lightpipe_hole_diameter"] / 2 + _HOLE_MARGIN, None, None))
    for ox, oy in coords["bezel_holes"]:
        panel_x, panel_y = oy, PANEL_H - ox
        wx, wy = to_work(panel_x, panel_y)
        holes.append(("bezel", wx, wy,
                      feats["bezel_hole_diameter"] / 2 + _HOLE_MARGIN, None, None))

    # Rectangular display cutouts
    dw = 42.5 / 2 + _HOLE_MARGIN
    dh = feats["display_cutout_height"] / 2 + _HOLE_MARGIN
    for ox, oy in coords["displays"]:
        panel_x, panel_y = oy, PANEL_H - ox
        wx, wy = to_work(panel_x, panel_y)
        holes.append(("display", wx, wy, None, dw, dh))

    return holes


def _point_in_hole(gx: float, gy: float, holes: list) -> bool:
    """Return True if (gx, gy) is inside any hole's avoidance zone."""
    for _, hx, hy, r, hw, hh in holes:
        if r is not None:
            if math.hypot(gx - hx, gy - hy) < r:
                return True
        else:
            if abs(gx - hx) < hw and abs(gy - hy) < hh:
                return True
    return False


def build_grid(angle_deg: float) -> tuple:
    """Build the probe grid, returning (xs, ys, grid_points, holes).

    grid_points: list of (col, row, x, y, skip) where skip=True means in a hole.
    xs, ys: the column/row coordinate arrays.
    """
    xs = [round(-GRID_X_HALF + i * 2 * GRID_X_HALF / (GRID_COLS - 1), 4)
          for i in range(GRID_COLS)]
    ys = [round(-GRID_Y_HALF + j * 2 * GRID_Y_HALF / (GRID_ROWS - 1), 4)
          for j in range(GRID_ROWS)]

    holes = _build_hole_list(angle_deg)

    points = []
    for row, gy in enumerate(ys):
        for col, gx in enumerate(xs):
            skip = _point_in_hole(gx, gy, holes)
            points.append((col, row, gx, gy, skip))

    n_probe  = sum(1 for _, _, _, _, s in points if not s)
    n_skip   = sum(1 for _, _, _, _, s in points if s)
    print(f"    Grid: {GRID_COLS}×{GRID_ROWS} = {len(points)} points  "
          f"({n_probe} probed, {n_skip} skipped over holes)")

    return xs, ys, points, holes


# === MAIN ===

def run(args):
    grbl = GrblConnection(args.port, BAUD, dry_run=args.dry_run)

    try:
        # [1] Check machine state
        print("\n[1/9] Checking machine state...")
        if not args.dry_run and args.port == PORT:
            result = subprocess.run(["pgrep", "-f", "gsender"], capture_output=True)
            if result.returncode == 0:
                print("ERROR: gSender is running. Close it first.", file=sys.stderr)
                sys.exit(1)
        grbl.check_state()

        # [2] Home
        print("\n[2/9] Homing machine (Z first for safety)...")
        try:
            grbl.send("$X", timeout=5)
        except (RuntimeError, TimeoutError):
            pass
        grbl.send("$HZ", timeout=HOMING_TIMEOUT)
        grbl.send("$HX", timeout=HOMING_TIMEOUT)
        grbl.send("$HY", timeout=HOMING_TIMEOUT)

        grbl.send("G53 G0 Z0")
        grbl.send(f"G53 G0 X{TOOL_CHANGE_X} Y{TOOL_CHANGE_Y}")
        pause("Install 3D probe (HLTNC). Ensure probe is connected.",
              dry_run=args.dry_run)
        grbl.send("G90")
        grbl.send("G53 G0 Z0")
        print("\n    Checking probe...")
        grbl.confirm_probe_trigger(
            "Touch the 3D probe tip to confirm it triggers.",
            dry_run=args.dry_run)

        # [3] Spoilboard probe
        print("\n[3/9] Probing spoilboard reference surface...")
        spoilboard_z = probe_spoilboard(
            grbl,
            x=SPOILBOARD_PROBE_X, y=SPOILBOARD_PROBE_Y,
            safe_z=SAFE_Z, travel=PROBE_TRAVEL_Z,
        )
        grbl.send("G53 G0 Z0")

        # [4] XY edge probing
        print("\n[4/9] Probing case edges for center and angle...")
        xy_probe_z = spoilboard_z + CASE_HEIGHT_NOMINAL - XY_PROBE_BELOW_SURFACE
        print(f"    XY probe Z: {xy_probe_z:.3f}mm")

        grbl.send(f"G53 G0 X{CASE_CENTER_X - CASE_HALF_WIDTH - APPROACH_CLEARANCE:.3f} Y{ANGLE_PROBE_Y_FRONT:.3f}")
        grbl.send(f"G53 G0 Z{xy_probe_z:.3f}")
        x_minus_front = probe_edge_double(grbl, "X", +1, "X- edge (front)")
        grbl.send("G53 G0 Z0")

        grbl.send(f"G53 G0 X{CASE_CENTER_X - CASE_HALF_WIDTH - APPROACH_CLEARANCE:.3f} Y{ANGLE_PROBE_Y_BACK:.3f}")
        grbl.send(f"G53 G0 Z{xy_probe_z:.3f}")
        x_minus_back = probe_edge_double(grbl, "X", +1, "X- edge (back)")
        grbl.send("G53 G0 Z0")

        grbl.send(f"G53 G0 X{CASE_CENTER_X + CASE_HALF_WIDTH + APPROACH_CLEARANCE:.3f} Y{CASE_CENTER_Y:.3f}")
        grbl.send(f"G53 G0 Z{xy_probe_z:.3f}")
        x_plus = probe_edge_double(grbl, "X", -1, "X+ edge")
        grbl.send("G53 G0 Z0")

        grbl.send(f"G53 G0 X{CASE_CENTER_X:.3f} Y{CASE_CENTER_Y - CASE_HALF_HEIGHT - APPROACH_CLEARANCE:.3f}")
        grbl.send(f"G53 G0 Z{xy_probe_z:.3f}")
        y_minus = probe_edge_double(grbl, "Y", +1, "Y- edge")
        grbl.send("G53 G0 Z0")

        grbl.send(f"G53 G0 X{CASE_CENTER_X:.3f} Y{CASE_CENTER_Y + CASE_HALF_HEIGHT + APPROACH_CLEARANCE:.3f}")
        grbl.send(f"G53 G0 Z{xy_probe_z:.3f}")
        y_plus = probe_edge_double(grbl, "Y", -1, "Y+ edge")
        grbl.send("G53 G0 Z0")

        # [5] Compute center and angle, set G54
        print("\n[5/9] Computing center and angle...")
        x_minus_avg = (x_minus_front + x_minus_back) / 2.0
        center_x    = (x_minus_avg + x_plus) / 2.0
        center_y    = (y_minus + y_plus) / 2.0
        dy          = ANGLE_PROBE_Y_BACK - ANGLE_PROBE_Y_FRONT
        dx          = x_minus_back - x_minus_front
        angle_deg   = math.degrees(math.atan2(dx, dy))

        print(f"    Case center: X={center_x:.4f} Y={center_y:.4f}")
        print(f"    Rotation angle: {angle_deg:.4f}°")

        if not args.dry_run:
            if x_minus_avg >= x_plus:
                raise RuntimeError(
                    f"X- edge ({x_minus_avg:.4f}) is not left of X+ ({x_plus:.4f}).")
            measured_width = abs(x_plus - x_minus_avg) - 2 * PROBE_TIP_RADIUS
            check_plausibility("case X width",   measured_width, EXPECTED_CASE_WIDTH,  MAX_WIDTH_ERROR)
            check_plausibility("case center X",  center_x,       CASE_CENTER_X,        MAX_CENTER_ERROR)
            check_plausibility("case center Y",  center_y,       CASE_CENTER_Y,        MAX_CENTER_ERROR)
            check_plausibility("rotation angle", angle_deg,      0.0,                  MAX_ANGLE_DEG)
            print("    Plausibility checks passed ✓")

        grbl.send(f"G53 G0 X{center_x:.3f} Y{center_y:.3f}")
        grbl.send("G10 L20 P1 X0 Y0")
        print("    G54 X0 Y0 set at case centre")

        # [6] Reference surface Z
        # Default offset (+20, 0): avoids the E button hole at centre (r=11.15mm).
        # 10mm clearance from nearest hole edge.
        if args.z_probe_offset:
            z_probe_x = center_x + args.z_probe_offset[0]
            z_probe_y = center_y + args.z_probe_offset[1]
            print(f"\n[6/9] Probing reference surface Z at offset ({args.z_probe_offset[0]}, {args.z_probe_offset[1]})...")
        else:
            z_probe_x = center_x + 20.0
            z_probe_y = center_y + 0.0
            print("\n[6/9] Probing reference surface Z at offset (+20, 0) (avoids centre button hole)...")
        grbl.send("G53 G0 Z0")
        grbl.send(f"G53 G0 X{z_probe_x:.3f} Y{z_probe_y:.3f}")
        grbl.send(f"G53 G0 Z-{SAFE_Z:.3f}")
        surface_z_ref = probe_z_surface(grbl, travel=PROBE_TRAVEL_Z)
        grbl.send("G53 G0 Z0")

        if not args.dry_run:
            case_height = surface_z_ref - spoilboard_z
            print(f"    Measured case height: {case_height:.3f}mm (expected {CASE_HEIGHT_NOMINAL}mm)")
            check_plausibility("case height", case_height, CASE_HEIGHT_NOMINAL, 5.0)

        # [7] Height map grid probing
        print("\n[7/9] Building surface height map...")
        print(f"    Building probe grid (angle={angle_deg:.4f}°)...")
        xs, ys, grid_points, holes = build_grid(angle_deg)

        # Grid: rows×cols array of Z offsets relative to surface_z_ref
        # Initialise with zeros; fill in probed values; skip = nearest neighbour fill later
        grid_data = [[0.0] * GRID_COLS for _ in range(GRID_ROWS)]
        probed    = [[False] * GRID_COLS for _ in range(GRID_ROWS)]

        # Z height for traversing between probe points: 3mm above reference surface
        traverse_z_machine = surface_z_ref + GRID_TRAVERSE_Z

        probe_count = 0
        for col, row, gx, gy, skip in grid_points:
            if skip:
                continue

            # Move to probe point in G54 work coords
            # First lateral move at traverse height, then probe
            grbl.send(f"G53 G0 Z{traverse_z_machine:.3f}")
            grbl.send(f"G90 G0 X{gx:.3f} Y{gy:.3f}")

            # Probe Z — only need ~10mm travel from traverse height
            grbl.send("G91")
            fast_result = grbl.probe(f"G38.2 Z-10.000 F{FEED_FAST}")
            grbl.send("G0 Z2.0")
            slow_result = grbl.probe(f"G38.2 Z-5.000 F{FEED_SLOW}")
            grbl.send("G90")

            point_z  = slow_result[2]
            z_offset = point_z - surface_z_ref
            grid_data[row][col] = round(z_offset, 4)
            probed[row][col]    = True
            probe_count += 1
            print(f"    [{probe_count:2d}] ({col},{row}) X={gx:+6.1f} Y={gy:+6.1f}  "
                  f"Z={point_z:.4f}  offset={z_offset:+.4f}mm")

        grbl.send("G53 G0 Z0")

        # Fill skipped grid points by nearest probed neighbour
        # (bilinear interpolation in HeightMap handles intermediate values;
        # we just need a reasonable value at each grid cell so the JSON is complete)
        print("\n    Filling skipped grid points by nearest-neighbour...")
        for col, row, gx, gy, skip in grid_points:
            if not skip:
                continue
            best_dist = float("inf")
            best_z    = 0.0
            for c2, r2, gx2, gy2, s2 in grid_points:
                if s2:
                    continue
                d = math.hypot(gx - gx2, gy - gy2)
                if d < best_dist:
                    best_dist = d
                    best_z    = grid_data[r2][c2]
            grid_data[row][col] = best_z

        # Save heightmap.json
        heightmap = {
            "x_min": xs[0],
            "x_max": xs[-1],
            "y_min": ys[0],
            "y_max": ys[-1],
            "cols":  GRID_COLS,
            "rows":  GRID_ROWS,
            "grid":  grid_data,
        }
        if not args.dry_run:
            HEIGHTMAP_FILE.write_text(json.dumps(heightmap, indent=2))
            print(f"    Saved: {HEIGHTMAP_FILE}")

        z_vals = [grid_data[r][c] for r in range(GRID_ROWS) for c in range(GRID_COLS)]
        print(f"    Z offset range: {min(z_vals):+.4f} .. {max(z_vals):+.4f} mm")

        # [8] Generate engraving G-code
        print("\n[8/9] Generating engraving G-code...")
        if not args.dry_run:
            import plates as plates_mod
            import config as plates_config
            import preview as plates_preview

            print(f"    Loading {ENGRAVING_YAML}...")
            conf = plates_config.load(str(ENGRAVING_YAML))

            # Apply angle to all features — plates uses origin=corner by default
            # but the engraving YAML uses landscape coords already baked in.
            # We just need to pass the heightmap.
            hm_data = json.loads(HEIGHTMAP_FILE.read_text())
            from toolpath.heightmap import HeightMap
            heightmap = HeightMap(
                x_min=hm_data["x_min"], x_max=hm_data["x_max"],
                y_min=hm_data["y_min"], y_max=hm_data["y_max"],
                grid=hm_data["grid"],
            )
            print(f"    Height map: {heightmap.rows}×{heightmap.cols} points  "
                  f"max deviation {heightmap.max_deviation:.3f}mm")

            layouts = plates_preview.resolve_layouts(conf)
            gcode   = plates_mod.generate_gcode(conf, layouts, heightmap=heightmap)
            errors  = plates_mod.validate_gcode(gcode)
            if errors:
                print("ERROR: G-code validation failed:", file=sys.stderr)
                for e in errors:
                    print(f"  {e}", file=sys.stderr)
                sys.exit(1)
            ENGRAVING_NC.write_text(gcode)
            print(f"    Written: {ENGRAVING_NC}")
        else:
            print("    [dry-run: skipping G-code generation]")

        # [9] Tool change: remove 3D probe, install V-bit
        print("\n[9/9] Tool change and Z probe...")
        grbl.send(f"G53 G0 X{TOOL_CHANGE_X} Y{TOOL_CHANGE_Y}")
        pause("Remove 3D probe. Install V-bit.", dry_run=args.dry_run)

        grbl.send("G53 G0 Z0")
        grbl.send(f"G53 G0 X{z_probe_x:.3f} Y{z_probe_y:.3f}")
        grbl.send(f"G53 G0 Z-{SAFE_Z:.3f}")
        pause(
            f"Place touch plate ({TOUCH_PLATE_THICKNESS}mm) on workpiece. "
            "Clip ground wire to V-bit.",
            dry_run=args.dry_run)
        print("\n    Checking touch plate...")
        grbl.confirm_probe_trigger(
            "Touch the V-bit to the touch plate to confirm circuit.",
            dry_run=args.dry_run)

        probe_z_double(grbl, travel=PROBE_TRAVEL_Z)
        grbl.send(f"G10 L20 P1 Z{TOUCH_PLATE_THICKNESS:.3f}")
        print(f"    G54 Z0 set (touch plate: {TOUCH_PLATE_THICKNESS}mm)")
        grbl.send("G53 G0 Z0")
        pause("Remove touch plate and ground wire.", dry_run=args.dry_run)

        print("\n" + "=" * 60)
        print("  ENGRAVE SETUP COMPLETE")
        print(f"  Angle:        {angle_deg:.4f}°")
        print(f"  Z range:      {min(z_vals):+.4f} .. {max(z_vals):+.4f} mm")
        print(f"  Height map:   {HEIGHTMAP_FILE}")
        print(f"  Engraving NC: {ENGRAVING_NC}")
        print("=" * 60)
        print(f"\n  Next: open gSender, connect, load and run:")
        print(f"    {ENGRAVING_NC}")

    except Exception as e:
        print(f"\n{'!' * 60}", file=sys.stderr)
        print(f"  ERROR: {e}", file=sys.stderr)
        print(f"  Sending feed hold...", file=sys.stderr)
        grbl.feed_hold()
        print(f"  Machine is in Hold state. Re-run to start over.", file=sys.stderr)
        print(f"{'!' * 60}", file=sys.stderr)
        sys.exit(1)
    finally:
        grbl.close()


def parse_args():
    p = argparse.ArgumentParser(
        description="Surface height map probing for engraving setup")
    p.add_argument("--port", default=PORT,
                   help=f"Serial port (default: {PORT})")
    p.add_argument("--dry-run", action="store_true",
                   help="Print commands without connecting to machine")
    p.add_argument("--z-probe-offset", type=float, nargs=2, default=None,
                   metavar=("X", "Y"),
                   help="Work coords offset from case centre for reference Z probe. "
                        "Default: (+20, 0) — solid surface clear of centre button hole. "
                        "Override if that spot is also cut through.")
    return p.parse_args()


if __name__ == "__main__":
    args = parse_args()
    run(args)

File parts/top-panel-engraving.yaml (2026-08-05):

# top-panel-engraving.yaml — Engraving for Hammond 1590DD top panel
#
# Panel: 181.8 × 113.8 mm LANDSCAPE (long axis = X left-right, short axis = Y)
# Origin: front-left corner of case top surface (plates default, origin=corner)
#
# ORIENTATION: Y=0 = FRONT of case (player side, button row 2 side)
#              Y=113.8 = BACK of case (encoder/connector side)
#
# Physical layout front-to-back (Y axis):
#   Y=0          front edge
#   Y=13.4       buttons row 2: B (X=15.9), D (X=90.9), F (X=165.9)
#   Y=36.2       displays:  D1 (X=53.4), D2 (X=128.4)
#   Y=65.4       buttons row 1: A (X=15.9), C (X=90.9), E (X=165.9)
#   Y=84.4       LEDs:      Mode (X=78.4), Mon (X=103.4)
#   Y=98.4       encoders:  Vol (X=53.9), Gain (X=128.9)
#   Y=113.8      back edge  (USB, MIDI, PWR)
#
# Connector positions (from drilling template):
#   Left edge  (X=0)    — outputs: Exp 2 (Y=21.9), Out 1 (Y=62.9), Out 2 (Y=83.1)
#   Right edge (X=181.8)— inputs:  In 2 (Y=30.7),  In 1 (Y=50.9),  Exp 1 (Y=91.9)
#   Back edge  (Y=113.8)— rear:    USB (X=37.0), MIDI Out (X=75.9), MIDI In (X=105.9), PWR (X=145.9)

plate:
  width: 181.8
  height: 113.8
  material: alu

tool:
  vbit_angle: 60
  vbit_depth_max: 0.3
  end_mill_dia: 3.0
  depth_per_pass: 0.1
  safe_z: 5.0
  retract_z: 1.0
  spindle_rpm: 10000

feeds:
  xy: 150
  z: 50

features:

  # ── BUTTON LABELS ─────────────────────────────────────────────────────────
  # Physical layout (landscape, Y=0=front, Y=113.8=back):
  #   D/E/F back row  at Y=65.4  (kicad_y=72,  closer to encoders)
  #   A/B/C front row at Y=13.4  (kicad_y=124, closer to player)
  #
  # D/E/F labels above back row (toward encoders): Y = 65.4 + 12.0 + 2.5 = 79.9
  # A/B/C labels above front row (toward back):   Y = 13.4 + 12.0 + 2.5 = 27.9

  - type: text
    text: "D"
    x: 22.0
    y: 49.9
    align: center
    font: /usr/share/fonts/TTF/RobotoCondensed-Bold.ttf
    size: 4.0
    strategy: vcarve

  - type: text
    text: "E"
    x: 90.9
    y: 49.9
    align: center
    font: /usr/share/fonts/TTF/RobotoCondensed-Bold.ttf
    size: 4.0
    strategy: vcarve

  - type: text
    text: "F"
    x: 159.8
    y: 49.9
    align: center
    font: /usr/share/fonts/TTF/RobotoCondensed-Bold.ttf
    size: 4.0
    strategy: vcarve

  - type: text
    text: "A"
    x: 22.0
    y: 28.9
    align: center
    font: /usr/share/fonts/TTF/RobotoCondensed-Bold.ttf
    size: 4.0
    strategy: vcarve

  - type: text
    text: "B"
    x: 90.9
    y: 28.9
    align: center
    font: /usr/share/fonts/TTF/RobotoCondensed-Bold.ttf
    size: 4.0
    strategy: vcarve

  - type: text
    text: "C"
    x: 159.8
    y: 28.9
    align: center
    font: /usr/share/fonts/TTF/RobotoCondensed-Bold.ttf
    size: 4.0
    strategy: vcarve

  # ── LED LABELS (light pipes) ──────────────────────────────────────────────
  # LEDs at Y=84.4. Place labels BESIDE (facing inward between the two holes):
  #   Mode right of its hole: X = 78.4 + 3.0 + 2.0 = 83.4, left-aligned
  #   Mon  left  of its hole: X = 103.4 - 3.0 - 2.0 = 98.4, right-aligned

  - type: text
    text: "Mode"
    x: 78.4
    y: 89.9
    align: center
    font: /usr/share/fonts/TTF/RobotoCondensed-Bold.ttf
    size: 2.5
    strategy: vcarve

  - type: text
    text: "Mon"
    x: 103.4
    y: 89.9
    align: center
    font: /usr/share/fonts/TTF/RobotoCondensed-Bold.ttf
    size: 2.5
    strategy: vcarve

  # ── ENCODER LABELS ────────────────────────────────────────────────────────
  # Encoders at Y=98.4 (near back). LEDs at Y=84.4 just in front.
  # Place labels BESIDE encoders in X:
  #   Vol  left  of encoder: X = 53.9 - 12.0 - 0.5 = 41.4, right-aligned
  #   Gain right of encoder: X = 128.9 + 12.0 + 0.5 = 141.4, left-aligned

  - type: text
    text: "Vol"
    x: 53.9
    y: 82.9
    align: center
    font: /usr/share/fonts/TTF/RobotoCondensed-Bold.ttf
    size: 3.5
    strategy: vcarve

  - type: text
    text: "Gain"
    x: 128.9
    y: 82.9
    align: center
    font: /usr/share/fonts/TTF/RobotoCondensed-Bold.ttf
    size: 3.5
    strategy: vcarve

  # ── LEFT EDGE — OUTPUTS (X=0) ─────────────────────────────────────────────
  # Boxes paired with right edge at same Y for visual alignment.
  # Shared Y rows: Exp row=87.5, Out1/In1 row=56.9, Out2/In2 row=26.3

  - type: rounded_rect
    x: 3.0
    y: 89.15
    width: 12.0
    height: 5.5
    sharp_corner: bottom-left
    corner_radius: 2.5

  - type: text
    text: "Exp 2"
    x: 9.0
    y: 91.9
    align: center
    font: /usr/share/fonts/TTF/RobotoCondensed-Bold.ttf
    size: 2.2
    strategy: vcarve

  - type: rounded_rect
    x: 3.0
    y: 46.90
    width: 12.0
    height: 5.5
    sharp_corner: top-left
    corner_radius: 2.5

  - type: text
    text: "Out 1"
    x: 9.0
    y: 49.65
    align: center
    font: /usr/share/fonts/TTF/RobotoCondensed-Bold.ttf
    size: 2.2
    strategy: vcarve

  - type: rounded_rect
    x: 3.0
    y: 27.95
    width: 12.0
    height: 5.5
    sharp_corner: bottom-left
    corner_radius: 2.5
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

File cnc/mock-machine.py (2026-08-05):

#!/usr/bin/env python3
"""
mock-machine.py — GRBL/FluidNC machine simulator for testing probe-setup.py.

Creates a virtual serial port pair using Python pty. Simulates a machine
with a Hammond 1590DD case mounted at a configurable position and angle.

Usage:
    python3 mock-machine.py                    # default: case at X=110 Y=190, angle=0°
    python3 mock-machine.py --angle 0.5        # simulate 0.5° rotation
    python3 mock-machine.py --offset-x 2.0    # case shifted 2mm in X
    python3 mock-machine.py --case-height 2.5  # case wall thickness

Then in another terminal:
    python3 probe-setup.py --port /tmp/cnc-sim

The mock prints all commands received and responses sent.
"""

import argparse
import math
import os
import pty
import re
import sys
import threading
import time

# === SIMULATED MACHINE GEOMETRY ===

# Machine travel limits (machine coordinates, negative = below home)
MACHINE_X_MAX = 220.0
MACHINE_Y_MAX = 380.0
MACHINE_Z_MAX = 95.0   # distance from Z home to Z limit

# Default case position (center, machine coords)
DEFAULT_CASE_CENTER_X = 110.0
DEFAULT_CASE_CENTER_Y = 190.0
DEFAULT_CASE_HALF_WIDTH = 113.8 / 2.0   # short axis (X)
DEFAULT_CASE_HALF_HEIGHT = 181.8 / 2.0  # long axis (Y)

# Spoilboard (fixture plate) is elevated — not at machine Z limit
# Measured: fixture plate top surface at 65mm below home
SPOILBOARD_Z_MACHINE = -65.0

# Probe tip radius (must match probe-setup.py)
PROBE_TIP_RADIUS = 2.0

# Virtual serial port symlink
SYMLINK = "/tmp/cnc-sim"


class MockMachine:
    """Simulates a GRBL/FluidNC controller with a mounted case."""

    def __init__(self, args):
        self.args = args

        # Simulated case geometry (with offset and angle)
        self.case_center_x = DEFAULT_CASE_CENTER_X + args.offset_x
        self.case_center_y = DEFAULT_CASE_CENTER_Y + args.offset_y
        self.angle_rad = math.radians(args.angle)

        # Case surface Z in machine coords
        # Spoilboard is at -MACHINE_Z_MAX, case sits on spoilboard
        self.case_surface_z = SPOILBOARD_Z_MACHINE + args.case_height

        # Crown: sinusoidal surface variation (highest at centre, zero at edges)
        # z_surface(x, y) = case_surface_z + crown * cos(pi*x/(2*hw)) * cos(pi*y/(2*hh))
        self.crown = args.crown

        # Touch plate: placed on top of case surface during Z probing
        # Simulated as always present for Z probes when over the case
        self.touch_plate_thickness = args.touch_plate

        # Simulated machine position (machine coords)
        self.pos = [0.0, 0.0, 0.0]  # X, Y, Z (Z=0 = home = top)
        self.homed = False
        self.state = "Idle"
        self.incremental = False  # G91 mode
        self.touch_plate_active = False  # set to True when touch plate is placed
        self.z_probe_count = 0  # track Z probe sequences (2nd = cutting tool + plate)

        # WCS G54 offsets
        self.g54 = [0.0, 0.0, 0.0]

    def _surface_z_at(self, machine_x, machine_y):
        """Return the case top surface Z at a given machine XY position.

        Applies sinusoidal crown: highest at centre, zero at edges.
        """
        if self.crown == 0.0:
            return self.case_surface_z
        # Position relative to case centre in case-local coords
        dx = machine_x - self.case_center_x
        dy = machine_y - self.case_center_y
        cos_a = math.cos(-self.angle_rad)
        sin_a = math.sin(-self.angle_rad)
        local_x = dx * cos_a - dy * sin_a
        local_y = dx * sin_a + dy * cos_a
        # Normalised position (0 at centre, 1 at edge)
        nx = local_x / DEFAULT_CASE_HALF_WIDTH
        ny = local_y / DEFAULT_CASE_HALF_HEIGHT
        # Clamp to case bounds
        nx = max(-1.0, min(1.0, nx))
        ny = max(-1.0, min(1.0, ny))
        # Cosine crown: positive Z = higher surface = probe triggers earlier
        z_offset = self.crown * math.cos(math.pi * nx / 2.0) * math.cos(math.pi * ny / 2.0)
        return self.case_surface_z + z_offset

    def _rotated_edge(self, nominal_x, nominal_y, probe_axis, direction):
        """Compute where a probe along probe_axis/direction contacts the case edge.

        Applies the simulated angle rotation to the case edges.
        Returns contact position in machine coords.
        """
        # Transform probe position into case-local coords
        # (reverse rotation by -angle)
        cx = self.case_center_x
        cy = self.case_center_y
        cos_a = math.cos(-self.angle_rad)
        sin_a = math.sin(-self.angle_rad)

        if probe_axis == "X":
            # Probing along X, Y is fixed
            # Case edge in local coords: x = ±half_width
            edge_local_x = DEFAULT_CASE_HALF_WIDTH * (-direction)
            # Transform edge point back to machine coords
            edge_machine_x = cx + edge_local_x * math.cos(self.angle_rad)
            edge_machine_y = cy + edge_local_x * math.sin(self.angle_rad)
            # Contact X = edge + probe tip offset
            contact_x = edge_machine_x + PROBE_TIP_RADIUS * direction
            return contact_x

        elif probe_axis == "Y":
            # Probing along Y at a given X position
            # Find Y of case edge at probe X in machine coords
            # Probe X in case-local coords
            probe_x_local = (nominal_x - cx) * cos_a - (self.pos[1] - cy) * sin_a
            # Edge Y in local coords: y = -half_height (Y- edge)
            edge_local_y = -DEFAULT_CASE_HALF_HEIGHT
            # Transform edge point back to machine coords at probe_x_local
            edge_machine_y = cy + probe_x_local * sin_a + edge_local_y * math.cos(self.angle_rad)
            # Contact Y = edge + probe tip offset
            contact_y = edge_machine_y + PROBE_TIP_RADIUS * direction
            return contact_y

        elif probe_axis == "Z":
            # Z probe — contact at case surface or spoilboard
            return None  # handled separately
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

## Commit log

2023-04-29 Initial revision (empty sketch)
    [pedalboard-case.FCStd]
2023-04-29 First paraemetric box
    [pedalboard-case.FCStd]
2023-04-29 Now its box
    [pedalboard-case.FCStd]
2023-04-29 Add lids
    [pedalboard-case.FCStd]
2023-04-29 Move to openscad
    [pedalboard-case.FCStd, pedalboard-case.scad]
2023-04-29 Add Workflow
    [pedalboard-case.scad]
2023-04-29 Generate STL CAD
    [pedalboard-case.stl]
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2023-04-29 Add lugs
    [pedalboard-case.scad]
2023-04-29 Fix cutout
    [pedalboard-case.scad]
2023-04-29 Add fixing screw holes
    [pedalboard-case.scad]
2023-04-29 Inner part of the lid is only 0.5 of the thickness
    [pedalboard-case.scad]
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2023-04-30 Make corner radius independent of lug radius
    [pedalboard-case.scad]
2023-04-30 Nicer corners and lid tolerance
    [pedalboard-case.scad]
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2023-04-30 Change holes sizes according to the specs
    [pedalboard-case.scad]
2023-04-30 Define the PCB height
    [pedalboard-case.scad]
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2023-04-30 Fine tune some values
    [pedalboard-case.scad]
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2023-04-30 Reduce lug height to allow fitting pcb
    [pedalboard-case.scad]
2023-04-30 Add counterbore for lug screws
    [pedalboard-case.scad]
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2023-04-30 Fine tune power jack
    [pedalboard-case.scad]
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2023-04-30 Thickness change of lid
    [pedalboard-case.scad]
2023-04-30 Revert "Fine tune power jack"
    This reverts commit 431353dc0cfb7fab64ee9e520a6c63f5321edda1.
    [pedalboard-case.scad]
2023-04-30 Revert "Fine tune power jack"
    This reverts commit 3886353222ef645b42f83c7fedac814ba7352bb2.
    [pedalboard-case.scad]
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2023-05-01 Set viewport for image generator
    [pedalboard-case.scad]
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2023-05-01 Refactor lugs by using children()
    [pedalboard-case.scad]
2023-05-01 Fix hole length for screw
    [pedalboard-case.scad]
2023-05-01 Refactor lugs on box
    [pedalboard-case.scad]
2023-05-01 Refactor lugs in lid
    [pedalboard-case.scad]
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2023-05-01 Use dia instead of radius for drilling holes
    [pedalboard-case.scad]
2023-05-01 Build some nut traps into the lugs
    [pedalboard-case.scad]
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2023-05-29 Fix actuator nut
    [actuator-nut.scad]
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2023-05-29 Fix assembly by defining pcb thickness
    [actuator-assembly.scad]
2023-05-30 Increase the size of the case to be able to mount the PCB
    [pedalboard-case.scad]
2023-06-03 Reduce complexity of actuator assembly model
    [actuator-assembly.scad]
2023-08-02 Add (cura) slicer project
    [led-ring-washer.3mf]
2023-08-02 Increase thickness of washer to allow 2.5mm thickness of https://www.hammfg.com/files/parts/pdf/1590DD.pdf
    [actuator-assembly.scad]
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2023-12-09 Add some basic drill jig
    [drill-jig.scad]
2023-12-10 Fix the angle for the side bushings
    [drill-jig.scad]
2023-12-10 Add correction for bushing
    [drill-jig.scad]
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2023-12-10 dynamically render the PCB
    [drill-jig.scad]
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2023-12-10 Add a bushing for the power plug
    [drill-jig.scad]
2023-12-10 Fix power plug (which is on the right)
    [drill-jig.scad]
2023-12-10 Sone tolarance for bushings
    [drill-jig.scad]
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2024-01-09 Add led ring washer for rotary encoder
    [led-ring--rotary-washer.scad]
2024-01-09 Fix file names
    [drill-jig.stl, led-ring-rotary-washer.scad]
2024-01-09 Remove pedalboard-case (anyways needs to be refactored
    [pedalboard-case.scad]
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2024-01-09 case is thinner: fix led-ring-washers
2024-01-09 reduce height of rotary led-ring washer
    [led-ring-rotary-washer.stl]
2024-01-09 tune the led-ring washers
    [display-bezel.scad, led-ring-rotary-washer.stl]
2024-01-09 First display bezel version
    [display-bezel.scad]
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2024-01-14 Only actuator, no washer
    [actuator-assembly.scad]
2024-01-14 Change color of display bezel
    [display-bezel.scad]
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2024-01-14 Set viewport rotation for washers
    [led-ring-rotary-washer.scad, led-ring-washer.scad]
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2024-01-14 Set drill jig color
    [drill-jig.scad]
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2024-01-14 Fix syntax errors
    [led-ring-rotary-washer.scad]
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2024-01-14 Fix color
    [light-pipe.scad]
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2024-10-09 Fix viewport
    [oled-display.scad, oled-display.stl]
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2024-11-10 Reduce the density of the LED ring washer
    [led-ring-rotary-washer.scad]
2024-11-10 First version of mounting Rack
    [display-mounting-rack.scad, display-mounting-rack.stl]
2024-11-11 Improve display mounting rack
    [display-mounting-rack.scad, display-mounting-rack.stl]
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2026-07-12 Add display cutout template (1:1 printable)
    34.5×36.7mm rectangular cutout for OLED glass panel (34.3×36.5mm
    + 0.1mm clearance). Includes button holes (ø12.5), encoder holes,
    and LED ring references. Derived from pedalboard-display KiCad
    footprint (OLED_128x128.kicad_mod).
2026-07-12 Add display cutout corners to drill jig
    8 corner bushings (ø3mm) for the two OLED display rectangular
    cutouts (34.5×36.7mm glass pass-through). Positions derived from
    pedalboard-display footprint centers at ±37.5mm X, back(34.8).
    [drill-jig.scad]
2026-07-12 Fix CI: use openscad/openscad:bookworm image
    The default (buster-based) image has EOL'd apt repos that return
    404. Switch to bookworm which is actively maintained.
2026-07-12 Add bezel M1.6 mounting holes to drill jig
    8 holes (ø1.7mm) for display bezel mounting screws, at ±15mm X
    and ±26mm Y from each display footprint center.
    [drill-jig.scad]
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2026-07-12 Refactor panel outputs: single source of truth from KiCad PCB
    All panel machining outputs now derive from one pipeline:
    pedalboard-display.kicad_pcb
    → extract-coords.py → top-panel-coords.json
    → top-panel-gcode.py → .nc (CNC G-code)
    → top-panel-dxf.py → .dxf (for CNC shop)
    → top-panel-template.py → .svg/.pdf (printable template)
    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
    [top-panel.dxf]
2026-07-12 Add generated CNC outputs and update README
    - top-panel.nc: G-code for CNC milling
    - top-panel.dxf: 2D profiles for CNC shop
    - Updated template with correct hole sizes
    - Added pipeline documentation to README
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2026-07-25 Add CNC fixture plate for 1590DD top panel milling
    Fixture plate screws to SRcnc wasteboard via M5 carriage holes (±60×±90mm).
    Case mounts open-side-down, screws through plate into case corner bosses.
    - fixture-plate.scad: 210×200×15mm MDF plate
    - 4x case holes: ø11mm counterbore 11mm deep + ø4mm shank through
    - 4x carriage holes: ø5.4mm through (M5, head on top)
    - Min screw length ~10mm, use ø10mm washer
    - fixture-plate-gcode.py: toolpath generator (4mm single flute, 800mm/min)
    - README.md: added fixture plate to parts table and CNC milling workflow
    - Makefile: added fixture target
    [fixture-plate.scad, fixture-plate.stl]
2026-07-25 Add 1590DD 3D model and ignore pycache
    [1590DD.stp]
2026-07-25 fixture-plate: add 2 center screws on long sides (0, ±57mm)
    [fixture-plate.scad, fixture-plate.stl]
2026-07-27 fixture-plate: moved to laenzlinger/cnc repo
    [fixture-plate.scad, fixture-plate.stl]
2026-07-29 Add flush-mount LED ring (plexiglass, CNC cut)
    - led-ring-flush.scad: stepped ring ø24mm/ø22mm/ø14mm, 2mm thick
    - led-ring-flush-gcode.py: G-code generator (4mm tool, 0.5mm/pass)
    - Sits flush in 1mm case recess, diffuses SK6805-EC15 LED light
    - 0.5mm spacer needed between PCB and case for LED clearance
    [led-ring-flush.scad]
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2026-07-29 Add flush-mount display window (plexiglass, CNC cut)
    - display-window-flush.scad: stepped rectangle 36.5×38.7mm / 34.1×36.3mm, 2mm thick
    - 2mm corner radius (matches 4mm endmill)
    - Solid window — OLED display visible through plexiglass
    - Same step retention principle as LED ring
    [display-window-flush.scad]
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2026-07-29 top-panel: light pipe through-hole ø5mm (0.5mm lip, better chip clearance)
2026-07-29 Add light pipe disc (ø6mm × 2mm plexiglass, CNC cut)
    - Simple solid disc, friction-fits into ø6mm recess + ø5mm through-hole
    - G-code generator supports multiple discs (--count)
    [lightpipe-disc.scad]
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2026-07-29 plexi-cut: increase part gap to 10mm for external contour clearance
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2026-07-29 fix: correct step order — inner (shallow) then outer (through)
    1. Center hole (full depth)
    2. Smaller diameter external (1mm deep) — creates step ledge
    3. Larger diameter external (full depth) — separates part
    The lip (ring between small and large diameter) remains on the
    bottom of the part for case retention.
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2026-07-29 plexi-cut: skip Z-2.0 pass, jump from Z-1.5 to Z-2.5 for clean separation
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2026-07-29 plexi-cut: revert to full through-cut (hot glue + screws + downcut should hold)
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2026-07-29 fix: external rect corner radius = part_r + tool_r (2+2=4mm toolpath for 2mm part radius)
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2026-07-31 panel_coords: swap X/Y for case mounted long axis along Y
    The case is physically mounted with the long axis (181.8mm) along
    the machine Y axis and the short axis (113.8mm) along X. The PCB
    layout in KiCad has the long axis as X. Apply the swap in to_cnc()
    so G-code coordinates match the physical fixture orientation.
2026-07-31 top-panel-gcode: fix full-circle arcs for grblHAL compatibility
    grblHAL rejects G2 arcs where XY endpoint equals current position
    (zero-length arc). For full circles, omit XY and only specify I/J.
    This is the standard way to command a full circle in GRBL/grblHAL.
2026-07-31 top-panel-gcode: remove bezel mounting holes (no longer needed)
2026-07-31 top-panel-gcode: replace non-ASCII chars in comments (ø→dia, ×→x)
    grblHAL returns error:1 on non-ASCII bytes in comments. Replace
    ø (diameter symbol) and × (multiplication sign) with ASCII.
2026-07-31 top-panel-gcode: remove empty lines from output
    grblHAL returns error:1 on empty lines (expected command letter).
    Filter out blank lines from the generated G-code.
2026-07-31 top-panel-gcode: add G-code validation and make test target
    Validates output for grblHAL compatibility:
    - No non-ASCII characters (error:1)
    - No empty lines (error:1)
    Run with: make test
2026-07-31 top-panel-gcode: strip all comments from output
    grblHAL/gSender have issues with parenthesized comments causing
    error:1. Remove all comment lines from generated G-code — the
    structure is clear enough from the command sequence alone.
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2026-07-31 top-panel-gcode: true helical entry (no straight plunges)
    Replace G1 Z plunge + G2 flat circle pattern with single G2 helical
    entry that descends while circling. Much easier on the tool in
    aluminium — no sudden axial load on entry.
2026-07-31 top-panel-gcode: add per-feature Z offset support
    Accept --z-offsets JSON file with per-feature Z corrections from
    surface probing. Each feature's Z commands are shifted by its local
    offset, compensating for cast case surface curvature.
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2026-08-01 top-panel-gcode: enlarge display cutouts (+5mm top, +3mm bottom)
    Display OLED was getting damaged by tight fit. Add 5mm clearance
    toward case center (top) and 3mm toward case edge (bottom).
    Both recess and through-cut are enlarged and shifted 1mm toward
    center to account for the asymmetric padding.
    Through-cut: 34.5x44.7mm (was 34.5x36.7mm)
    Recess: 36.5x46.7mm (was 36.5x38.7mm)
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2026-08-01 display-window: update dimensions for wider display cutout
    Match the new asymmetric display cutout (42.5x36.7mm through,
    44.5x38.7mm recess). Window lip fills the recess, step drops
    into the through-cut with 0.4mm clearance.
    [display-window-flush.scad]
2026-08-01 display-window: add 0.3mm clearance per side for fit tolerance
    Parts were too tight in the case recesses. Add 0.3mm clearance on
    each side (0.6mm total) for both the lip (recess) and step (cutout).
    Clearance is a single parameter — easy to adjust if needed.
    [display-window-flush.scad]
2026-08-01 display-window: reduce clearance to 0.15mm (snug fit)
    [display-window-flush.scad]
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2026-08-01 side-panel-template: fix side length (120mm), mirror back, add center line
    - Left/right sides are 120mm (short axis), not 188mm
    - Back view mirrored (looking from outside)
    - Center line on all strips
    - USB-A: two 8mm drill holes with crosshairs, file to rectangular
    - Reference: left = front of case
2026-08-01 side-panel-template: fix PCB against back wall, correct heights
    - PCB sits flush against back wall (no gap at back)
    - 3.5mm jacks use correct height (pcb_top + 2.5mm, not +8mm)
    - Barrel jack height = pcb_top + 4mm
    - Side jack positions recalculated with 0 offset from back
2026-08-01 side-panel-template: barrel jack at fixed 39mm (from jig), height=24.4mm
    Barrel jack is independent of PCB, positioned from the old tested
    jig. Height matches 6.35mm jacks (24.4mm from bottom).
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2026-08-01 side-panel-template: heights from top, align template to top edge
    Reworked height calculation: case_wall(3) + display_pcb(1.6) + spacer(17)
    = 21.6mm from top to main PCB surface. Heights measured from top edge
    which is the alignment reference for the paper template.
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2026-08-02 Remove 3D printed drill jig (superseded by side-panel-template SVG/PDF)
    [drill-jig.scad]
2026-08-02 README: replace drill jig with side panel template
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2026-08-02 Remove DXF output (superseded by G-code)
    [top-panel.dxf]
2026-08-02 light-pipe: reduce length from 18mm to 3mm
    [light-pipe.scad]
2026-08-02 README: add fixture plate image to G-code entry
2026-08-02 README: move fixture plate image to correct row
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2026-08-02 Move CNC probe setup into this repo (from cnc repo)
    The probe-setup.py script belongs with the case project, not the
    machine repo. Includes mock-machine.py, run_test.py, and Makefile.
    Updated README with full CNC milling workflow documentation
    including cutting parameters, rework instructions, and testing.
    [mock-machine.py, probe-setup.py, run_test.py]
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2026-08-02 light-pipe: reduce body to 2mm (total 3mm with lip)
    [light-pipe.scad]
2026-08-02 top-panel-gcode: button 3 through-hole cuts 3mm deeper (screw post clearance)
    Fixes #41. Button 3 (X=-8.5, Y=0) is over the center screw post.
    Cut 3mm deeper than standard to remove post material and allow
    the PCB to clear.
2026-08-02 top-panel-gcode: shift displays +2.6mm in X (connector clearance)
    Fixes #40. Displays shifted toward back (positive X) to clear
    MIDI/USB connectors on the back edge.
2026-08-02 top-panel-gcode: fix display offset direction (-2.6mm X toward back)
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2026-08-05 Update top panel engraving design
    - Landscape orientation (181.8×113.8mm, Y=0=front)
    - Correct button mapping from PCB: D/E/F back row, A/B/C front row
    - D/F/A/C shifted inward (±6mm) to clear I/O label boxes
    - I/O labels use drilling template centerlines (both sides verified)
    - In1=Out1, In2=Out2 share same Y for visual consistency
    - MIDI In/Out sharp corners point to exact jack centerlines
    - USB and PWR labels removed (self-explanatory)
    - Left/right I/O boxes horizontal (12mm wide), same style as back edge
    [top-panel-engraving.yaml]
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2026-08-05 Add engrave-setup.py and refactor shared CNC infrastructure
    grbl.py — shared module:
    Extracted from probe-setup.py: GrblConnection, probe_edge_double,
    probe_z_double, probe_z_surface, probe_spoilboard, check_plausibility, pause.
    Both probe-setup.py and engrave-setup.py import from here.
    engrave-setup.py — new script:
    9-step workflow: home, 3D probe, spoilboard Z ref, XY edges + angle,
    G54 X0Y0, reference surface Z, 6x10 height map grid (38 of 60 points,
    skipping all hole positions), heightmap.json, engraving.nc via
    plates.py --heightmap, V-bit tool change, touch plate Z probe.
    mock-machine.py — --crown option:
    Sinusoidal surface crown simulation (cos*cos, highest at c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
    [engrave-setup.py, grbl.py, mock-machine.py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]
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2026-08-05 Integrate plates as library (no subprocess)
    engrave-setup.py now imports plates directly:
    import plates, config, preview, toolpath.heightmap
    rather than spawning a subprocess. Eliminates the hardcoded
    PLATES_PY path and subprocess overhead.
    Dependency management:
    - pyproject.toml declares plates + pyserial as dependencies
    - Makefile installs into the plates project venv (Python 3.13)
    rather than creating a separate venv, avoiding the need to
    rebuild shapely/pygeoops from source for a different Python.
    - sys.path.insert ensures plates.py top-level module is importable
    (setuptools editable install only covers subpackages).
    run_test.py uses the plates venv Python expli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
    [engrave-setup.py, run_test.py]
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2026-08-05 Fix engraving label positions (from overlay review)
    1. Vol/Gain: 3mm further from encoder ring (x: 41.4->38.4, 141.4->144.4)
    2. Mode/Mon: 3mm further from lightpipe holes (x: 73.4->70.4, 108.4->111.4)
    3. A/B/C: 2mm inward toward displays (y: 27.9->29.9)
    D/E/F: 2mm inward toward displays (y: 50.9->52.9)
    4. In1/Out1 boxes: upper edge on jack centerline Y=56.9
    (sharp_corner: top-left/top-right, y: 51.4, text_y: 54.15)
    [top-panel-engraving.yaml]
2026-08-05 Revert "Fix engraving label positions (from overlay review)"
    This reverts commit 194fc72a60b3d7a28dcc5c421141f885def37ac3.
    [top-panel-engraving.yaml]
2026-08-05 Fix engraving label positions (from overlay review)
    1. Vol/Gain: moved below encoders, centred (y=82.9, distance=15.5mm matching E)
    2. Mode/Mon: moved above LED holes toward back, centred (y=89.9)
    3. A/B/C: 1mm toward back (y=28.9); D/E/F: 1mm toward player (y=49.9)
    4. In1/Out1: sharp corner on upper side (top-left/top-right), box clear
    of D/E/F LED ring (top at Y=52.4, 1mm from ring bottom at Y=53.4)
    [top-panel-engraving.yaml]
2026-08-05 engrave-setup: default Z probe offset (+20,0) to avoid centre button hole
    The E button hole is at the panel centre (r=11.15mm). The probe would
    fall in. Default offset (+20,0) gives 10.3mm clearance from nearest hole.
    [engrave-setup.py]
2026-08-05 engraving-overlay: add probe point markers
    - Cyan dots: 42 probed height map grid points
    - Grey dots: 18 skipped (over holes)
    - Green crosshair: Z reference probe point (+20,0 from centre)
2026-08-05 Change grid to 8x7 (42 probed, 14 skipped, 25x18mm spacing)
    [engrave-setup.py]
2026-08-05 Fix display avoidance radius: use actual cut (42.5mm) not recess
    Was using display_cutout_width/2 + 5mm (recess padding) which skipped
    6 valid probe points around the display edges. Now uses the actual
    through-cut width (42.5mm) + probe_tip (2mm) + margin (1mm).
    8x7 grid: 48 probed, 8 skipped (was 40 probed, 16 skipped).
    [engrave-setup.py]
2026-08-05 Fix work coord conversion in hole avoidance (panel->work mapping)
    The panel->work coordinate transform was wrong in both engrave-setup.py
    and engraving-overlay.py. The correct empirically-verified mapping is:
    work_x = -(panel_y - PANEL_H/2) (machine X = short axis = panel Y)
    work_y = panel_x - PANEL_W/2 (machine Y = long axis = panel X)
    This was also corrected in the overlay's grid_points() function which
    now uses origin=center work coords directly (matching engrave-setup)
    rather than converting through panel coords.
    Both now agree: 35 probed, 21 skipped for the 8x7 grid.
    [engrave-setup.py]
2026-08-05 Switch to 7x8 grid (46 probed, 10 skipped, 18x25mm spacing)
    Best probe/skip ratio after fixing coordinate transform bug.
    Previous 8x7 gave only 35 probed; 7x8 gives 46 — same 56 total points.
    [engrave-setup.py]
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
